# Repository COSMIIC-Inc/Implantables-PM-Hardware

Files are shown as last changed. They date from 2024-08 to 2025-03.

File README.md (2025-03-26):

# Implantables-PowerModule-Hardware Read Me

## Contents
This repository is home to the 3D CAD and PCB design files of the PM2 - Power Module in the COSMIIC System.
Further documentation is available at **[docs.cosmiic.org/Implantables/PM-Module](https://docs.cosmiic.org/Implantables/PM-Module)**

## Licensing
Hardware-related files are licensed to open source users by COSMIIC under the CERN Open Hardware License - Permissive - v2 (CERN-OHL-P-2.0). Refer to the **[license text](https://ohwr.org/cern_ohl_p_v2.txt)** (also embedded in the repository as **LICENSE.txt**) and **[user guide](https://ohwr.org/project/cernohl/-/wikis/uploads/8a6b5d01f71c207c49493e4d114d61e6/cern_ohl_p_v2_howto.pdf)** to understand your permissions.

Hardware-related files includes, but is not limited to...

- Mechanical Design
    - 3D CAD Files (parts and assemblies, multiple file types)
    - Mechanical Drawings (parts and assemblies, mulitple file types)
- PCB Design
    - Fabrication (Gerber and Drill files)
    - Assembly (Pick and Place, BOM)
    - Archive (Schematics, multiple file types)

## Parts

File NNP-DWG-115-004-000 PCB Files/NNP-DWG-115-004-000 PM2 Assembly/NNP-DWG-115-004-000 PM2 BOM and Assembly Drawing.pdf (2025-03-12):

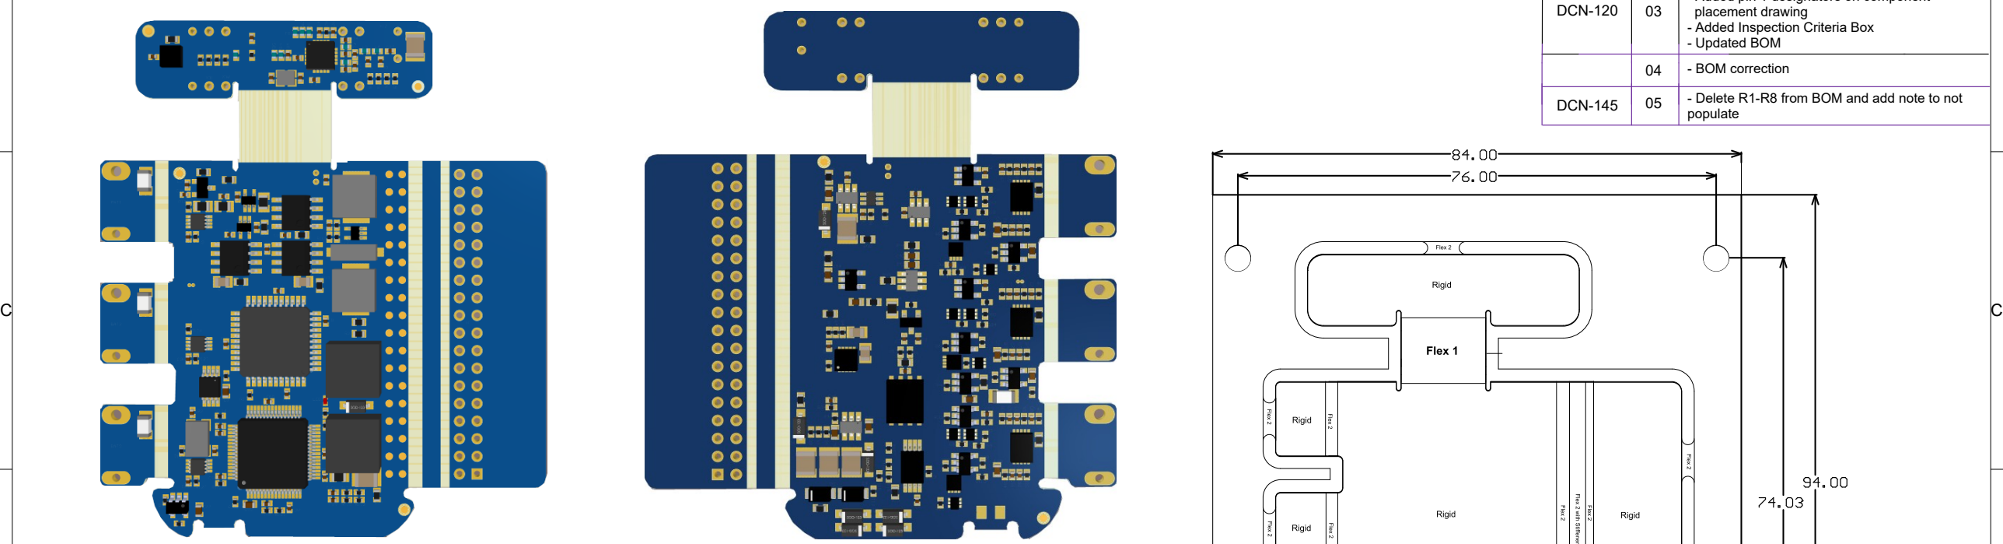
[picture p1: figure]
placement drawing - Added Inspection Criteria Box - Updated BOM; - BOM correction; populate; DCN-145

D | D

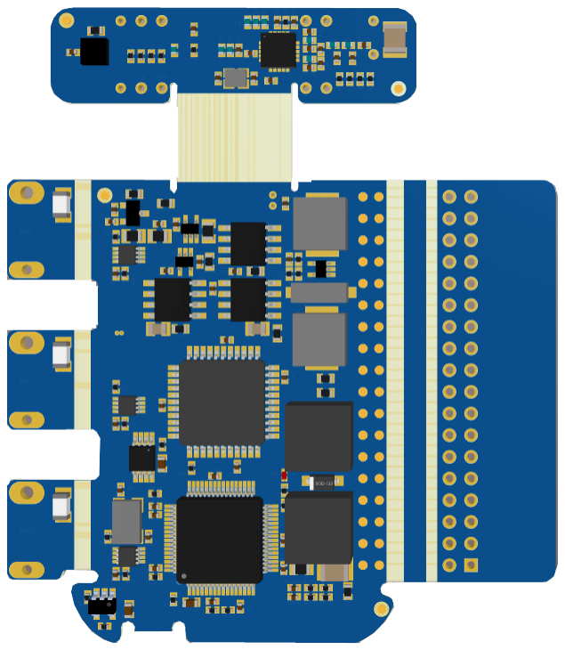
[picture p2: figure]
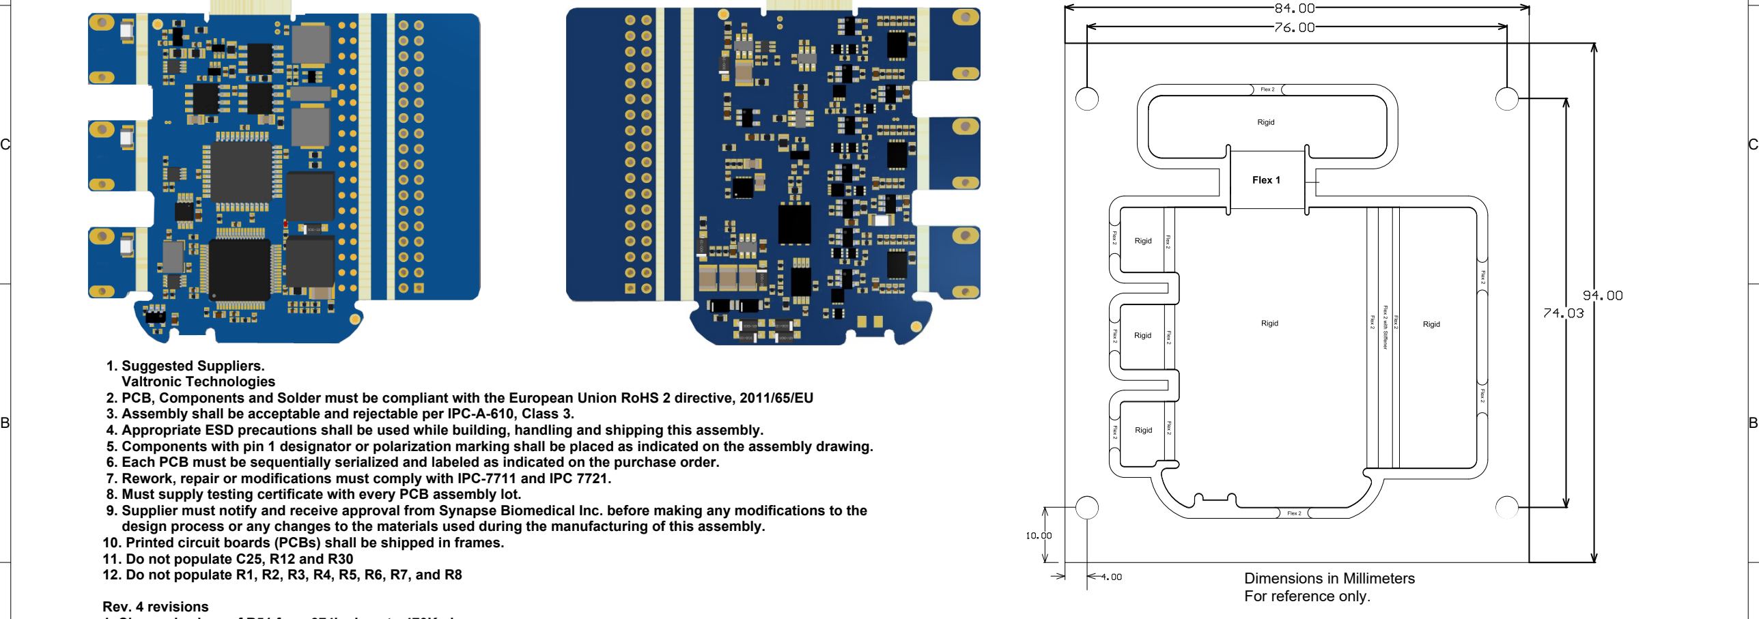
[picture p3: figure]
1. Suggested Suppliers. Valtronic Technologies; 11. Do not populate C25, R12 and R30; Rev. 4 revisions; Dimensions in Millimeters For reference only.

A | A
INSPECTION REQUIRED | YES | NO | DRAWN K. Kowalski | 07-18-2022
| X
CERTIFICATE REQUIRED | YES | NO | CHECKED T. Crish | 07-18-2022
| X

Insp. Item
A | Inspect to current 51-2001-08 Inspection Procedure
| REF 51-2001-09 Inspect report
C | RoHS Certificate required

D
51-2001 | 5

NNP Power Module (PM1)
PCB Assembly Drawing

DOCUMENT NAME

DOCUMENT NO. | REV

NEXT ASSY
SCALE:

B

SIZE
FINISH

MATERIAL

BY | DATE

SHEET 1 OF 6

ECN | REV | DESCRIPTION
DCN-104 DCN-110 | | Initial Engineering Released. Never Build.

N/A

- Updated BOM (refer to Page 1 of the Schematic for changes)
- Added component placement
- Updated Notes
Top | Bottom
2. PCB, Components and Solder must be compliant with the European Union RoHS 2 directive, 2011/65/EU
3. Assembly shall be acceptable and rejectable per IPC-A-610, Class 3.
4. Appropriate ESD precautions shall be used while building, handling and shipping this assembly.
5. Components with pin 1 designator or polarization marking shall be placed as indicated on the assembly drawing.
6. Each PCB must be sequentially serialized and labeled as indicated on the purchase order.
7. Rework, repair or modifications must comply with IPC-7711 and IPC 7721.
8. Must supply testing certificate with every PCB assembly lot.
9. Supplier must notify and receive approval from Synapse Biomedical Inc. before making any modifications to the design process or any changes to the materials used during the manufacturing of this assembly.
10. Printed circuit boards (PCBs) shall be shipped in frames.

### 12. Do not populate R1, R2, R3, R4, R5, R6, R7, and R8

### 1. Changed values of R51 from 374k ohms to 470K ohms

2. Changed R52 from 43.2k ohm to 69.8K Ohm.
3. Changed resistor R14 from 0.0 ohm to 3k ohm.
4. Changed R106 and R107 from 10.0k ohm to 1.5k ohm.
5. Changed C40, C41, C42 and C56 to a smaller package Capacitor.

Rev. 5 revision

### 1. Added note to not populate R1-R8 2. Delete R1-R8 from BOM

DCN-120 03

- Updated Notes
- Added pin 1 designators on component
N/A | N/A
Note: Program CPLD U7 with PM20 Code | N/A

INSPECTION CRITERIA

E

05 - Delete R1-R8 from BOM and add note to not

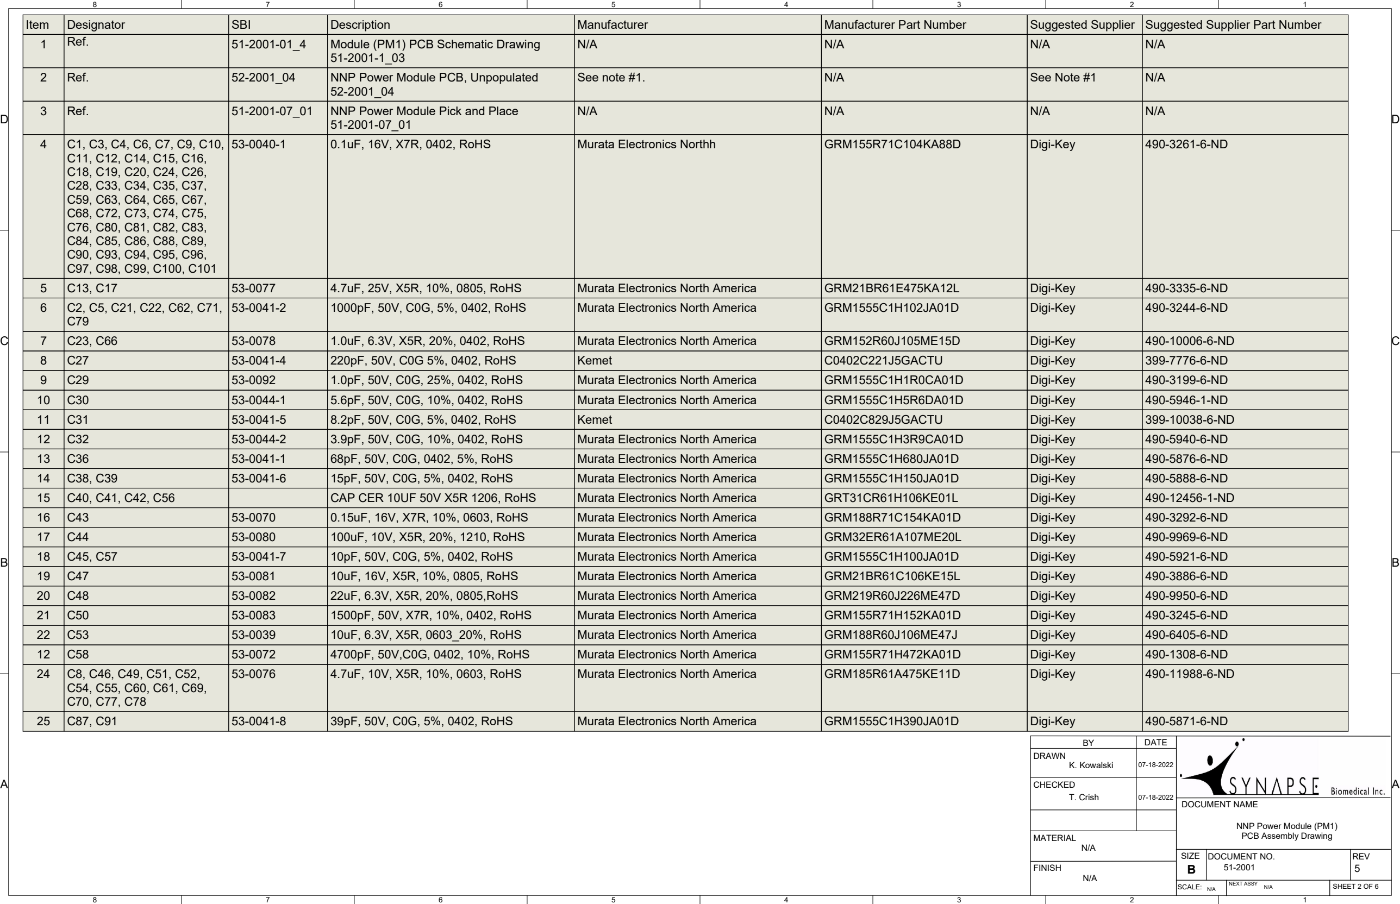
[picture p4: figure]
DATE; CHECKED T. Crish; DRAWN K. Kowalski; DOCUMENT NAME; NNP Power Module (PM1); Item; Designator Ref.; Ref.; SBI 51-2001-01_4; Description Module (PM1) PCB Schematic Drawing 51-2001-1_03 NNP Power Module PCB, Unpopulated 52-2001_04 NNP Power Module Pick and Place 51-2001-07_01 0.1uF, 16V, X7R, 0402, RoHS; 4.7uF, 25V, X5R, 10%, 0805, RoHS 1000pF, 50V, C0G, 5%, 0402, RoHS; 1.0uF, 6.3V, X5R, 20%, 0402, RoHS 220pF, 50V, C0G 5%, 0402, RoHS 1.0pF, 50V, C0G, 25%, 0402, RoHS 5.6pF, 50V, C0G, 10%, 0402, RoHS 8.2pF, 50V, C0G, 5%, 0402, RoHS 3.9pF, 50V, C0G, 10%, 0402, RoHS 68pF, 50V, C0G, 0402, 5%, RoHS 15pF, 50V, C0G, 5%, 0402, RoHS CAP CER 10UF 50V X5R 1206, RoHS 0.15uF, 16V, X7R, 10%, 0603, RoHS 100uF, 10V, X5R, 20%, 1210, RoHS 10pF, 50V, C0G, 5%, 0402, RoHS 10uF, 16V, X5R, 10%, 0805, RoHS 22uF, 6.3V, X5R, 20%, 0805,RoHS 1500pF, 50V, X7R, 10%, 0402, RoHS 10uF, 6.3V, X5R, 0603_20%, RoHS 4700pF, 50V,C0G, 0402, 10%, RoHS 4.7uF, 10V, X5R, 10%, 0603, RoHS; 39pF, 50V, C0G, 5%, 0402, RoHS; Manufacturer; See note #1.; Murata Electronics Northh; Murata Electronics North America Murata Electronics North America; Murata Electronics North America Kemet Murata Electronics North America Murata Electronics North America Kemet Murata Electronics North America Murata Electronics North America Murata Electronics North America Murata Electronics North America Murata Electronics North America Murata Electronics North America Murata Electronics North America Murata Electronics North America Murata Electronics North America Murata Electronics North America Murata Electronics North America Murata Electronics North America Murata Electronics North America; Murata Electronics North America; Manufacturer Part Number; GRM155R71C104KA88D; GRM21BR61E475KA12L GRM1555C1H102JA01D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

D | D
C | C
B | B
A | A
DRAWN K. Kowalski | 07-18-2022
CHECKED T. Crish | 07-18-2022

NNP Power Module (PM1)

DOCUMENT NAME

BY | DATE
N/A | N/A | SHEET 3 OF 6

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
D1, D2, D3, D4, D6, D7, D9

D10

D5, D8
F1, F2, F3, F4

FB1, FB2, FB3, FB4, FB5
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
LED1
R17, R27, R101
R10
R100, R104
R102
R11, R13, R16, R18, R19,
R20, R21, R22, R24, R29,
R31, R32, R37, R39, R45,
R46, R47, R48, R49, R50
R14

R118
R125
R15, R60, R61, R65, R68,
R77, R78, R81, R83, R92,
R93, R96, R98
R23
R25

54-0084

54-0112

54-0111
54-0113

54-0114
53-0094
53-0089-4
53-0089-3
53-0089-2
53-0089-1
53-0090
54-0115
54-0116
54-0117
53-0035
53-0048
53-0049-22
53-0088
53-0049-35
53-0075

53-0049-36
53-0049-11
53-0049-4

53-0023-03
53-0084

0.1uF, 50V, X7R, 10%, 0603, RoHS Schottky Diode, 40V, 500mA, SOD123, RoHS
Schottky Diode, 20V, 1000mA, SOD123W, RoHS
Zener Diode, 15V, 1W, DI123, RoHS
PTC Resettable, 500mA, 0.4 ohm, 6V, 1206, RoHS
Ferrite, 100mA, 1ohm, 0402, RoHS Ferrite, 250mA, 1.1ohm, 0402, RoHS
47nF, 0402, 5%, RoHS
33nH, 0402, 5%, RoHS
27nH, 0402, 5%, RoHS
18nH, 0402, 5%, RoHS
47uH, 830mA, 20%, RoHS
10uH, 1.6A, 20%, 3030, RoHS
10uH, 1.1A, 2626, 20%, RoHS
2.7uH, 1.8A, 2626, 20%, RoHS
LED, Red, 0402, 20mA ,2V, 140mcd, RoHS 0.0 ohm, 1/16W, 0402, RoHS
7.5k ohm, 0.1%, 1/16W, 0402, RoHS
0.0 ohm, 1/8W, 0805, RoHS
38.3k ohm, 1%, 1/16W, 0402, RoHS 0.0 ohm, 1/16W, 0603, RoHS

3.0k ohm, 1/5W, 1%, 0402, RoHS

549k ohm, 1%, 1/16W, 0402, RoHS 150k ohm, 1%, 1/16W, smd, 0402, RoHS 1.0k ohm 1% 1/16W smd 0402 RoHS

20 ohm, 1%, 1/8W, 0805, RoHS 100k ohm, 0.1%, 1/8W, 0805, RoHS

Murata Electronics North America Micro Commercial Co

NXP Semiconductors

Diodes Incorporated
Littelfuse Inc.

Laird-Signal Integrity Products Murata Electronics North America Coilcraft
Coilcraft
Coilcraft
Coilcraft
Pulse
Pulse
Panasonic Electronic Components Panasonic Electronic Components Lumex Opto/Components Inc. Vishay Dale
Vishay Dale
Vishay Dale
Vishay Dale
Vishay Dale

Vishay Dale

Vishay Dale
Vishay Dale
Vishay Dale

Vishay Dale
Vishay Dale

GRM188R71H104KA93D
MBR0540-TP

PMEG2010BER,115

DFLZ15Q-7
1206L050YR

HZ0402A601R-10
BLM15HG102SN1D
0402CS-47NXJLU
0402CS-33NXJLU
0402CS-27NXJLW
0402CS-18NXJLU
P1166.473NLT
P1166.103NLT
ELL-6RH100M
ELL-6RH2R7M
SML-LX0402SIC-TR
CRCW04020000Z0ED
TNPW04027K50BEED
CRCW08050000Z0EA
CRCW040238K3FKED
CRCW06030000Z0EA

CRCW04023K00FKEDHP

CRCW0402549KFKED
CRCW0402150KFKED
CRCW04021K00FKED

CRCW080520R0FKEA
TNPW0805100KBEEA

Supplier
Digi-Key
Digi-Key

Digi-Key

Digi-Key
Digi-Key

Digi-Key
Digi-Key
MOUSER
MOUSER
MOUSER
MOUSER
MOUSER
Digi-Key
Digi-Key
Digi-Key
Digi-Key
Digi-Key
Digi-Key
Digi-Key
Digi-Key
Digi-Key

Digi-Key

Digi-Key
Digi-Key
Digi-Key

Digi-Key
Digi-Key

Supplier Part Number
490-1519-6-ND
MBR0540TPMSDKR-ND

568-6503-6-ND

DFLZ15Q-7DIDKR-ND
F2112DKR-ND

240-2364-1-ND
490-3999-6-ND
994-0402CS-47NXJLU
994-0402CS-33NXJLU
994-0402CS-27NXJLW
994-0402CS-18NXJLU
673-P1166.473TNLT
553-1790-6-ND
PCD1345DKR-ND
PCD1339DKR-ND
67-1878-6-ND
541-0.0JDKR-ND
TNP7.50KDADKR-ND
541-0.0ADKR-ND
541-38.3KLDKR-ND
541-0.0GDKR-ND

541-CRCW04023K00FKEDHPCT-ND

541-549KLDKR-ND
541-150KLDKR-ND
541-1.00KLDKR-ND

541-20.0CDKR-ND
TNP100KABDKR-ND

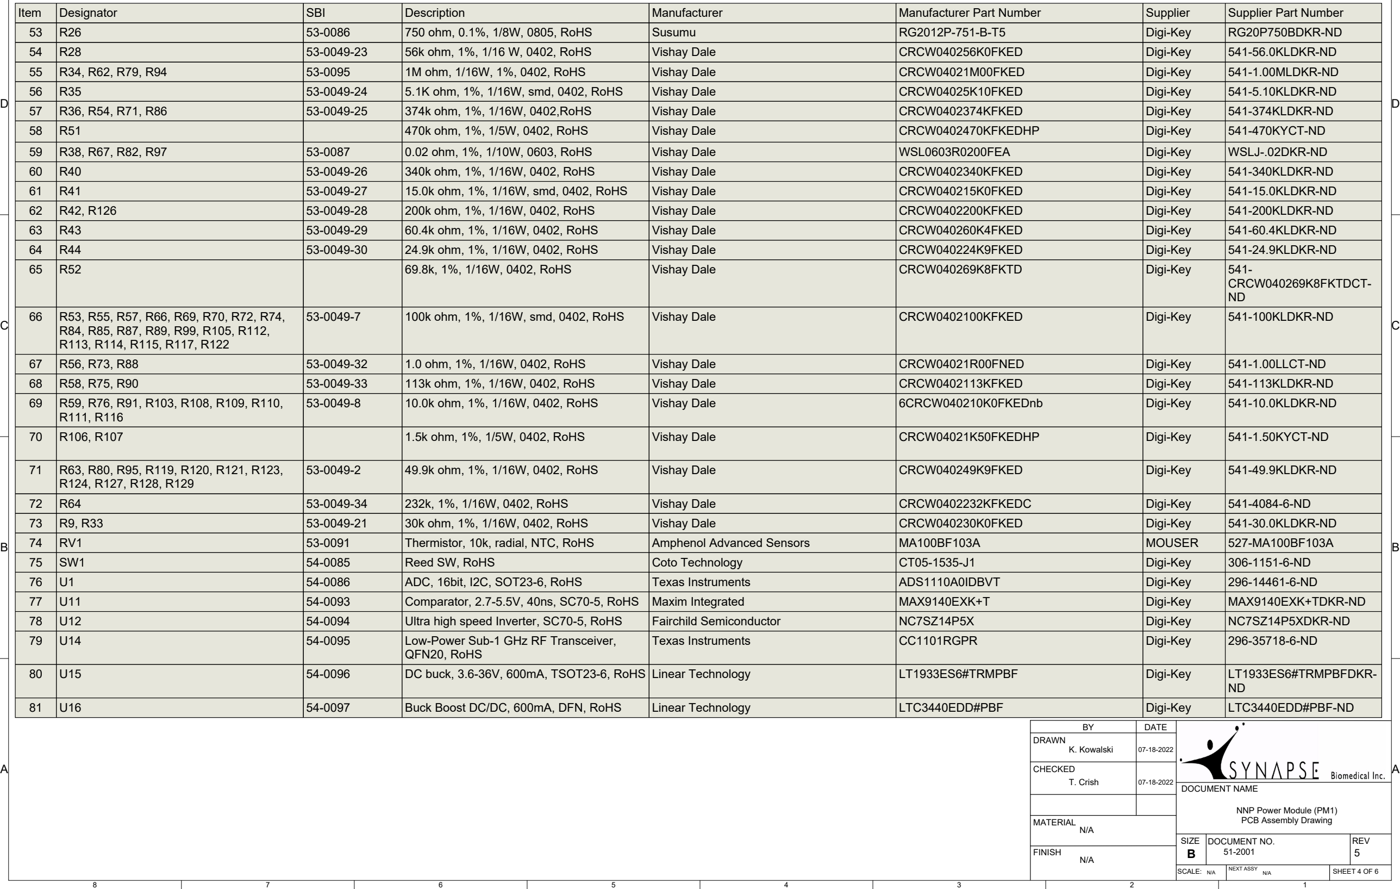
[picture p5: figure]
DATE; CHECKED T. Crish; DRAWN K. Kowalski; DOCUMENT NAME; NNP Power Module (PM1); 750 ohm, 0.1%, 1/8W, 0805, RoHS 56k ohm, 1%, 1/16 W, 0402, RoHS 1M ohm, 1/16W, 1%, 0402, RoHS 5.1K ohm, 1%, 1/16W, smd, 0402, RoHS 374k ohm, 1%, 1/16W, 0402,RoHS 470k ohm, 1%, 1/5W, 0402, RoHS; 0.02 ohm, 1%, 1/10W, 0603, RoHS 340k ohm, 1%, 1/16W, 0402, RoHS 15.0k ohm, 1%, 1/16W, smd, 0402, RoHS 200k ohm, 1%, 1/16W, 0402, RoHS 60.4k ohm, 1%, 1/16W, 0402, RoHS 24.9k ohm, 1%, 1/16W, 0402, RoHS 69.8k, 1%, 1/16W, 0402, RoHS; 100k ohm, 1%, 1/16W, smd, 0402, RoHS; 1.0 ohm, 1%, 1/16W, 0402, RoHS 113k ohm, 1%, 1/16W, 0402, RoHS 10.0k ohm, 1%, 1/16W, 0402, RoHS; 1.5k ohm, 1%, 1/5W, 0402, RoHS; 49.9k ohm, 1%, 1/16W, 0402, RoHS; 232k, 1%, 1/16W, 0402, RoHS 30k ohm, 1%, 1/16W, 0402, RoHS Thermistor, 10k, radial, NTC, RoHS Reed SW, RoHS ADC, 16bit, I2C, SOT23-6, RoHS Comparator, 2.7-5.5V, 40ns, SC70-5, RoHS Ultra high speed Inverter, SC70-5, RoHS Low-Power Sub-1 GHz RF Transceiver, QFN20, RoHS DC buck, 3.6-36V, 600mA, TSOT23-6, RoHS; Buck Boost DC/DC, 600mA, DFN, RoHS; Susumu Vishay Dale Vishay Dale Vishay Dale Vishay Dale Vishay Dale; Vishay Dale Vishay Dale Vishay Dale Vishay Dale Vishay Dale Vishay Dale Vishay Dale; Vishay Dale; Vishay Dale Vishay Dale Vishay Dale; Vishay Dale Vishay Dale Amphenol Advanced Sensors Coto Technology Texas Instruments Maxim Integrated Fairchild Semiconductor Texas Instruments; Linear Technology; RG2012P-751-B-T5 CRCW040256K0FKED CRCW04021M00FKED CRCW04025K10FKED CRCW0402374KFKED CRCW0402470KFKEDHP; WSL0603R0200FEA CRCW0402340KFKED CRCW040215K0FKED CRCW0402200KFKED CRCW040260K4FKED CRCW040224K9FKED CRCW040269K8FKTD; CRCW0402100KFKED; CRCW04021R00FNED CRCW0402113KFKED 6CRCW040210K0FKEDnb; CRCW04021K50FKEDHP; CRCW040249K9FKED; CRCW0402232KFKEDC CRCW040230K0FKED MA100BF103A CT05-1535-J1 ADS1110A0IDBVT MAX9140EXK+T NC7SZ14P5X CC1101RGPR; LT1933ES6#TRMPBF; LTC3440EDD#PBF; Digi-Key Digi-Key Digi-Key Digi-Key; Digi-Key Digi-Key Digi-Key Digi-Key Digi-Key Digi-Key Digi-Key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

D | D
C | C
B | B
A | A
DRAWN K. Kowalski | 07-18-2022
CHECKED T. Crish | 07-18-2022

NNP Power Module (PM1)

DOCUMENT NAME

BY | DATE

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
U17, U26, U34, U42
U18

U19

U2, U13
U20
U21
U22, U30, U38
U23, U29, U31, U37, U39,
U45
U24, U32, U40
U25, U33, U41
U27, U35, U43
U28, U36, U44
U3
U4
U46

U47
U48, U49, U50

U5
U6

U7
U8, U9, U10
Y1
Y2

54-0079

54-0098

54-0087
54-0099
54-0100
54-0101
54-0102

54-0103
54-0104
54-0105
54-0106
54-0088
54-0089
54-0107

54-0060
54-0108

54-0074
54-0090

54-0091
54-0092
54-0109
54-0110

Current Monitor, 2.5V-20V, 1%, RoHS Voltage inverter, 1.15-5.5V, 50mA, SOT23-6, RoHS
Buck Boost, DC/DC, 350mA, SOT23-5, RoHS
Ref, 2.048V, 5uA, SOT23-3, RoHS
DC, Booster, 2.4-16V, TSOT23
DIGPOT, 100Kohm, I2C, SC70
Ideal diode, 2.6-5.5V, 2.6A, SOT23-5, RoHS MOSFET 2N, 60V, 0.305A, RoHS

Dual P-Channel Mosfet, SOT563, RoHS VLDO, 150mA, SOT23-5, RoHS
Op Amp, R-R, 1uA, RoHS
LI-ION Gas Guage, I2C, QFN10, RoHS Flash, 32Mbit, SPI, SO8
RAM, 256Kbit, SPI, TSSOP8, RoHS
uC 1.8Vcore 3.3VIO 16kB RAM 256kB FLA QFP
Voltage detector Reset, SC70-5, RoHS Analog Switch, DUAL, 2-Channel, SSOP8, RoHS
Tri-axis accelerometer, I2C, LGA10, RoHS Precision µPower Oscillator, ADJ 1.7-5.5V,5MHz, uSOP8, RoHS
CPLD, 3.3V, 10nS, XPLA3, QFP48, RoHS Pin driver, 15nS, 40 MHz, SO8, RoHS Xtal, 26MHz, 2.5x2.0x0.7mm, RoHS Crystal 10MHz 20pF HC-49US

Diodes Incorporated
ON Semiconductor

Texas Instruments

Maxim Integrated
Linear Technology
Analog Devices Inc.
Linear Technology
Vishay Siliconix

Vishay Siliconix
Linear Technology
Linear Technology
Texas Instruments
Adesto Technologies
MicroChip Technology
NXP Semiconductors

Texas Instruments
Texas Instruments

Kionix
Linear Technology

Xilinx Inc.
Intersil
NDK
ECS Inc.

ZXCT1010E5TA
NCP1729SN35T1G

LM3670MF-1.8/NOPB

MAX6018AEUR21+T
LT3467AES6#TRMPBF
AD5246BKSZ100-RL7
LTC4411ES5#TRMPBF
SI1026X-T1-GE3

SI1023X-T1-GE3
LTC1844ES5-SD#TRMPBF
LT6003CDC#TRMPBF
BQ27200DRKR
AT45DB321E-SHF-T
23K256T-I/ST
LPC2129FBD64/01,15

TPS3805H33DCKR
TS5A23166DCUR

KXTE9-2050
LTC6930IMS8-5.00#PBF

XCR3032XL-10VQG44C
EL7156CSZ
NX2520SA-26.000000MHZ
ECS-100-20-30B-TR

Digi-Key

Digi-Key

Digi-Key
Digi-Key
Digi-Key
Digi-Key
Digi-Key

Digi-Key
Digi-Key
Digi-Key
Digi-Key
Digi-Key
Digi-Key
Digi-Key

Digi-Key
Digi-key

MOUSER
Digi-Key

Digi-Key
Digi-Key
Digi-Key
Digi-Key

ZXCT1010DKR-ND
NCP1729SN35T1GOSDKR-ND

LM3670MF-1.8/NOPBDKR-ND

MAX6018AEUR21+TDKR-ND
LT3467AES6#TRMPBFDKR-ND
AD5246BKSZ100RLDKR-ND
LTC4411ES5#TRMPBFDKR-ND
SI1026X-T1-GE3CT-ND

SI1023X-T1-GE3CT-ND
LTC1844ES5-SD#TRMPBFDKR-ND LT6003CDC#TRMPBFDKR-ND
296-17521-6-ND
1265-1097-6-ND
23K256T-I/STDKR-ND
568-4315-ND

296-13407-6-ND
296-17906-6-ND

912-KXTE9-2050
LTC6930IMS8-5.00#PBF-ND

122-1957-ND
EL7156CSZ-T7DKR-ND
644-1063-6-ND
XC1117DKR-ND

## Drawing for reference only

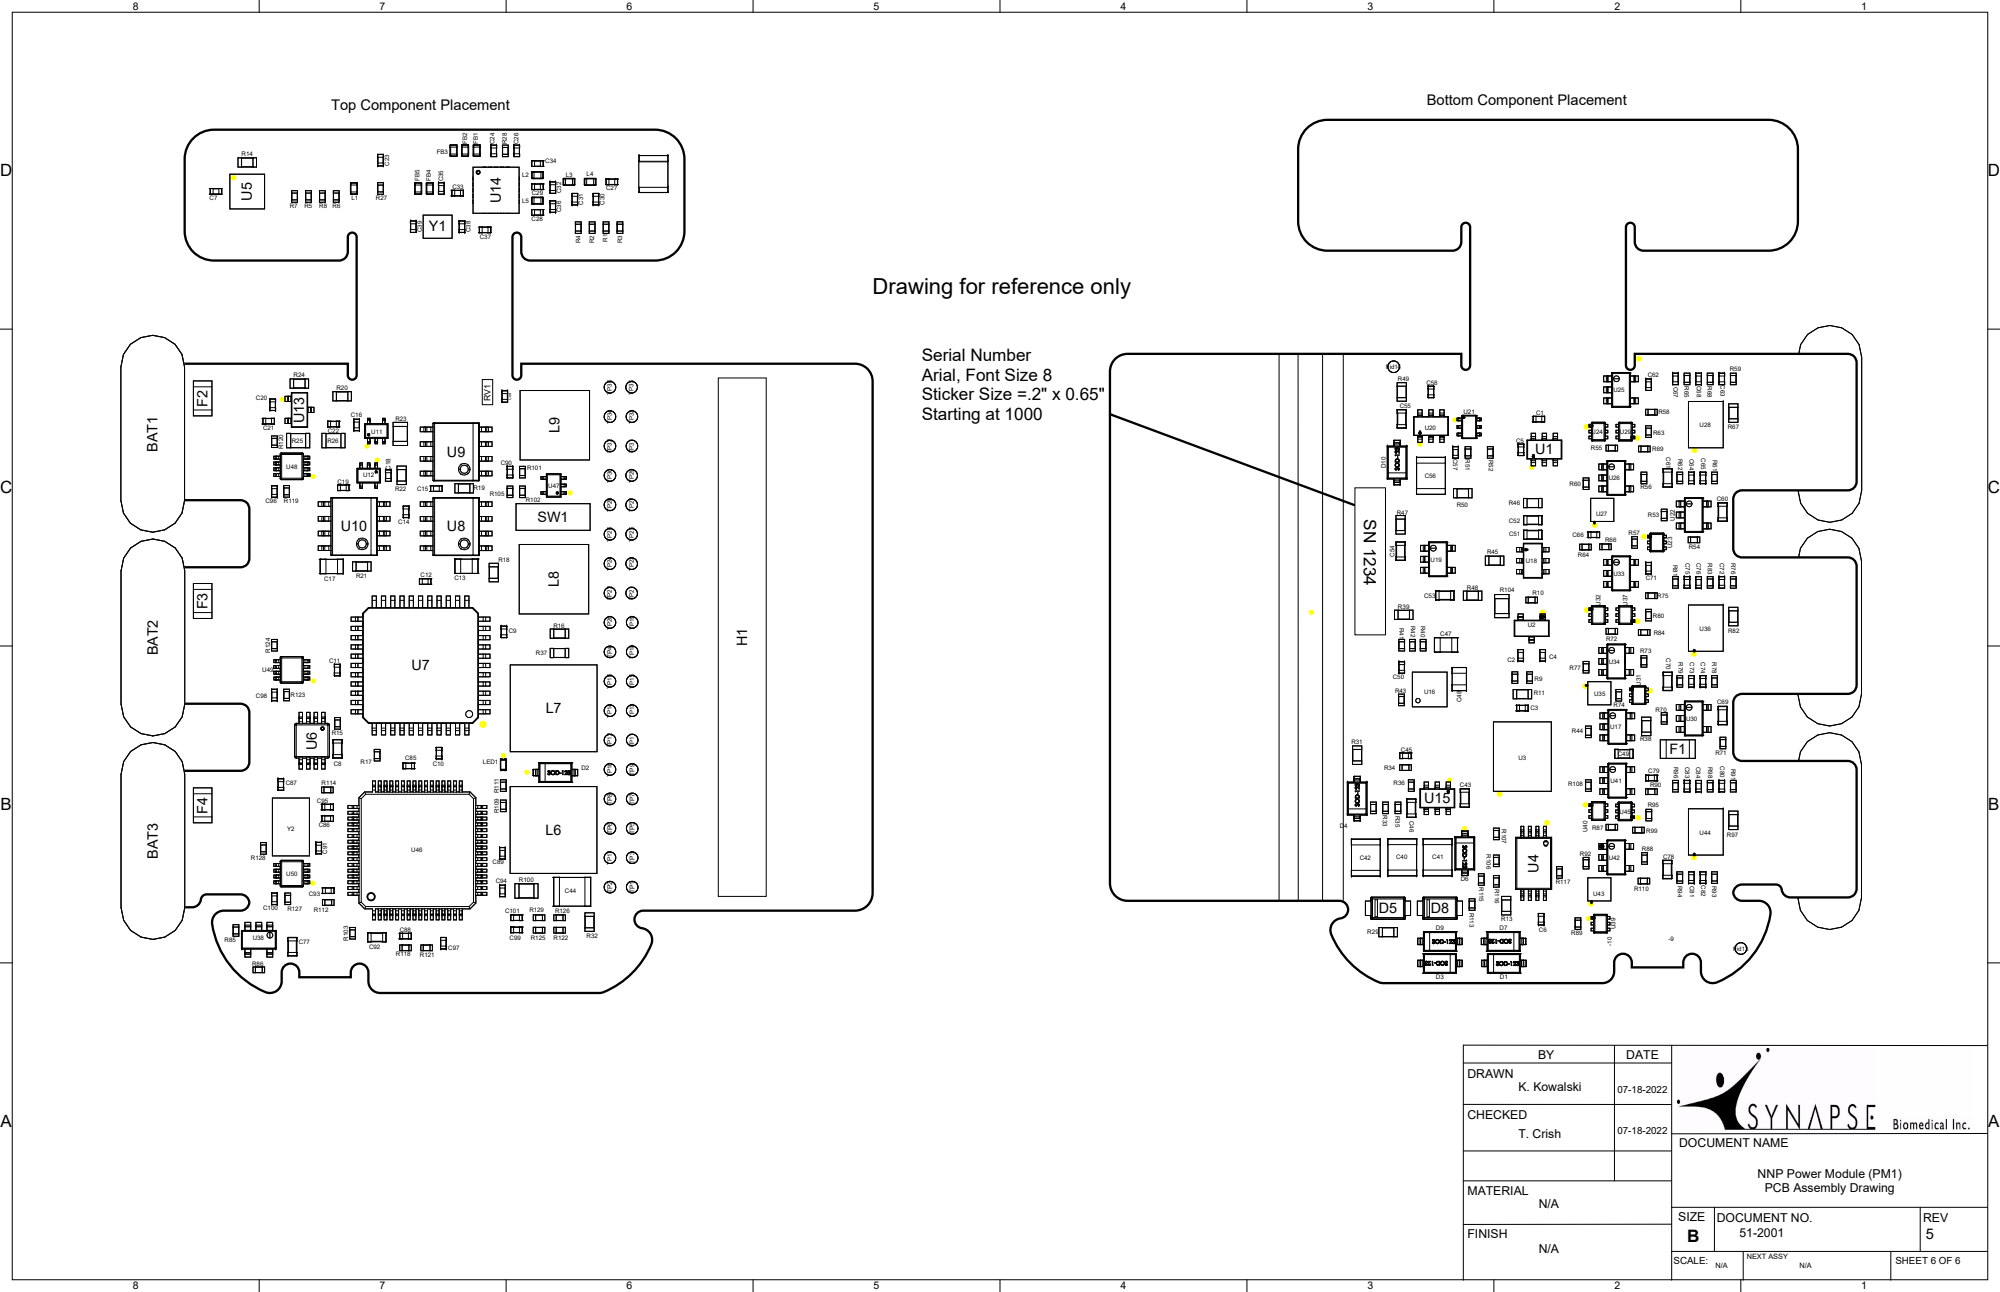
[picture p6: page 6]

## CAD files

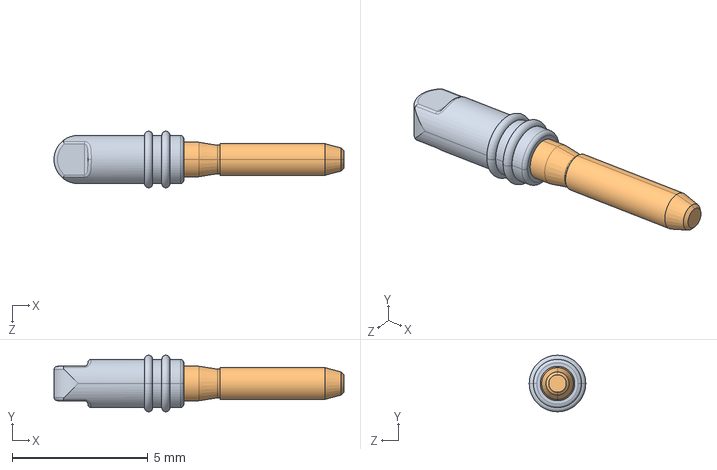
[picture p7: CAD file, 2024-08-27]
Mechanical Design CAD Files/STEP Files/NNP-DWG-115-001-000 Port Plug Assembly.STEP
10.7 x 2.08 x 2.08 mm
NNP-DWG-110-001-000 Port Plug, Handle Overmold, Blue_21-2008 Overmold- Blue
NNP-DWG-110-002-000 Port Plug, Body

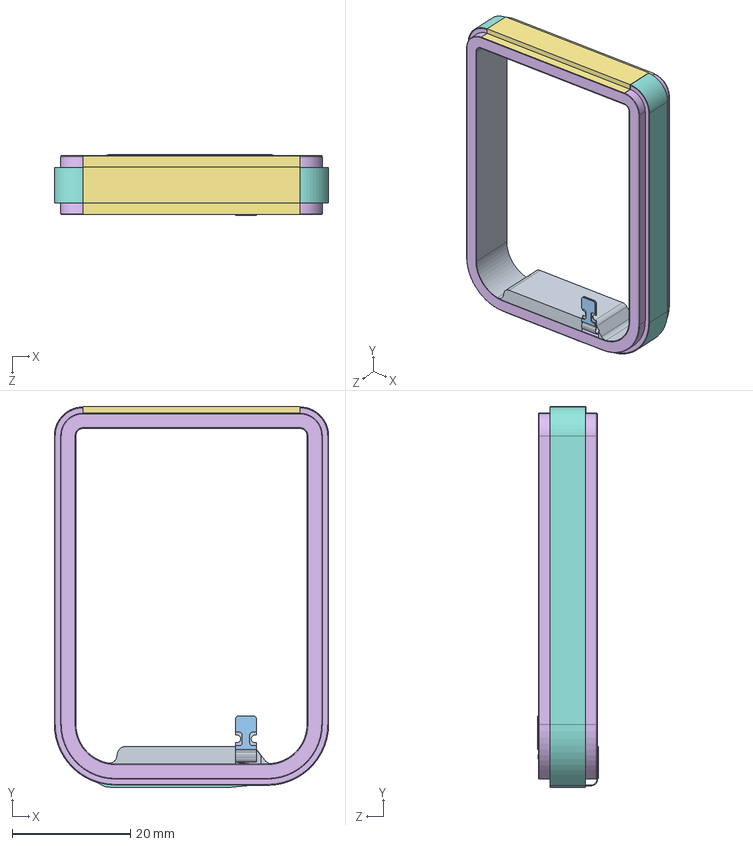
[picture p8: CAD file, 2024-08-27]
Mechanical Design CAD Files/STEP Files/NNP-DWG-115-006-000 Power Module Coil Assembly.STEP
46.5 x 64.5 x 10.3 mm
NNP-DWG-110-017-000 Power Module, Daughter Board
NNP-DWG-110-018-000 Capacitor, 0.22 uF x 2
NNP-DWG-110-019-000 Capacitor, 0.47 uF x 2
NNP-DWG-110-025-000 Recharge Coil

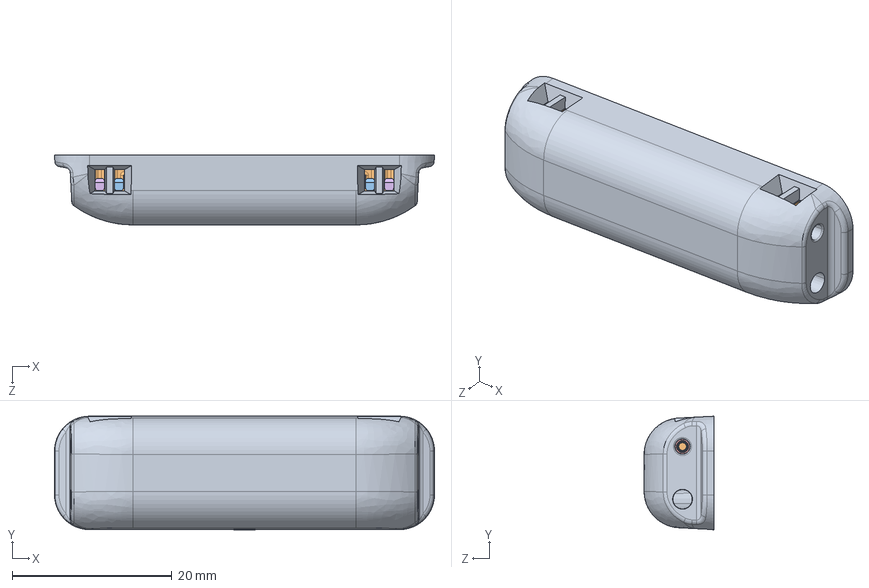
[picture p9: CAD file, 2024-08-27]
Mechanical Design CAD Files/STEP Files/NNP-DWG-115-008-000 Power Module Header Assembly, 2 Port.STEP
47.7 x 14.2 x 8.76 mm
NNP-DWG-110-016-000 Pre-Molded Header, 2-Port
NNP-DWG-110-008-000 BalSeal Block_symmetric part x 2
NNP-DWG-130-011-000 Balseal, Conductor x 2
NNP-DWG-130-012-001 Balseal, Spring, CW x 2
NNP-DWG-130-013-001 Balseal, Washer, CW x 2
NNP-DWG-130-013-002 Balseal, Washer, CCW x 2
NNP-DWG-130-012-002 Balseal, Spring, CCW x 2
NNP-DWG-130-011-000 Balseal, Conductor_No Groove x 2
NNP-DWG-130-005-000 BalSeal Assembly, Internal Cavity Single Seal x 2

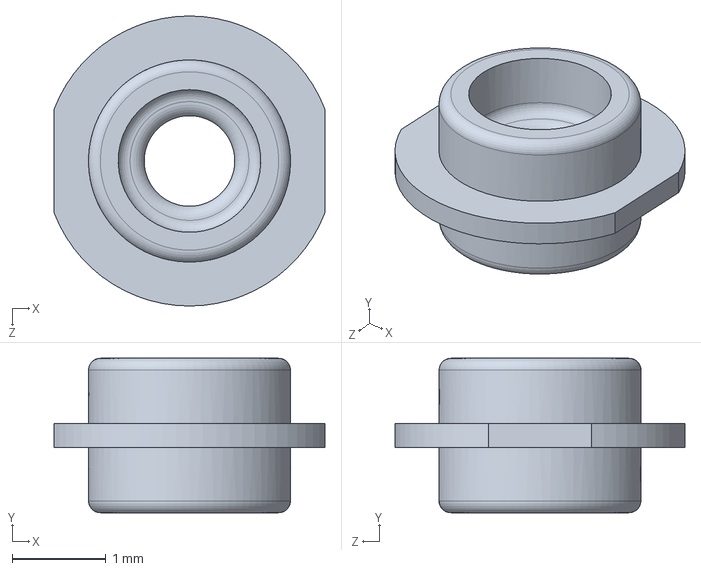
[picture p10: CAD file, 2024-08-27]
Mechanical Design CAD Files/SolidWorks Native Files/NNP-DWG-130-005-000 BalSeal Assembly, Internal Cavity Single Seal.SLDPRT
2.90 x 1.65 x 3.10 mm

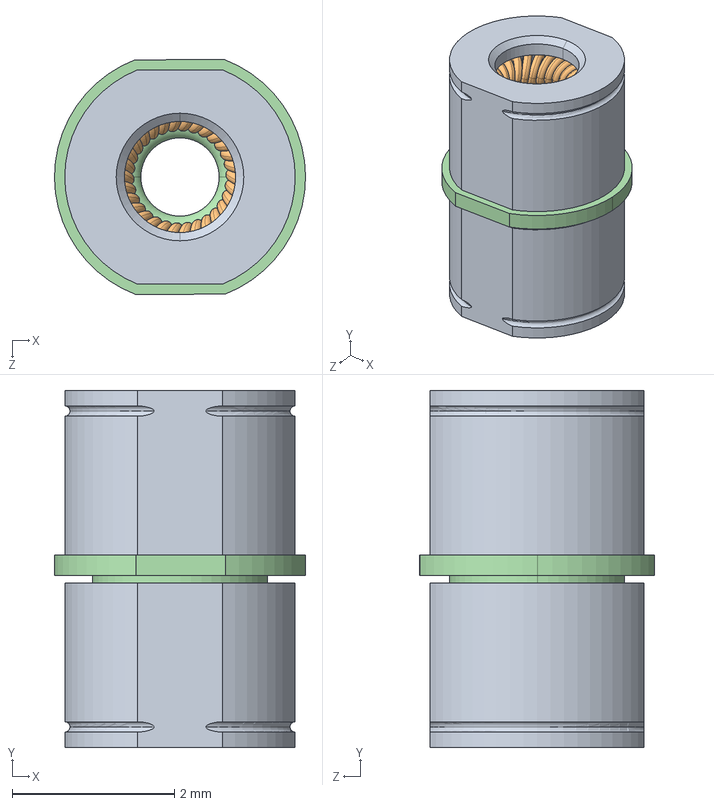
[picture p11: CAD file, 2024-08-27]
Mechanical Design CAD Files/STEP Files/NNP-DWG-135-004-000 SA, BalSeal Stack Assembly.STEP
3.10 x 4.41 x 2.90 mm
NNP-DWG-130-011-000 Balseal, Conductor x 2
NNP-DWG-130-012-001 Balseal, Spring, CW
NNP-DWG-130-013-001 Balseal, Washer, CW
NNP-DWG-130-013-002 Balseal, Washer, CCW
NNP-DWG-130-012-002 Balseal, Spring, CCW
NNP-DWG-130-005-000 BalSeal Assembly, Internal Cavity Single Seal_COMPRESSED

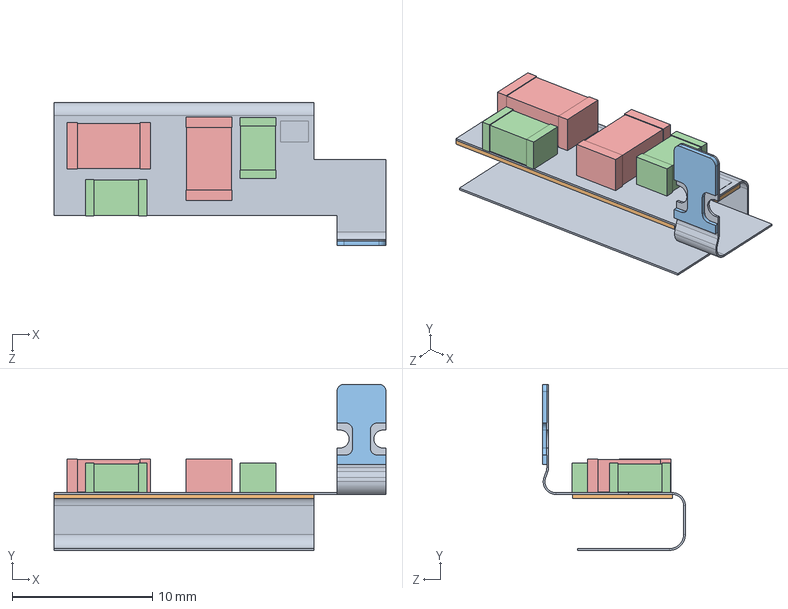
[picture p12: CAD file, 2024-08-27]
Mechanical Design CAD Files/STEP Files/NNP-DWG-115-003-000 SA, Near Field PCB Assembly.STEP
23.7 x 11.9 x 10.2 mm
NNP-DWG-110-017-000 Power Module, Daughter Board
NNP-DWG-110-018-000 Capacitor, 0.22 uF x 2
NNP-DWG-110-019-000 Capacitor, 0.47 uF x 2

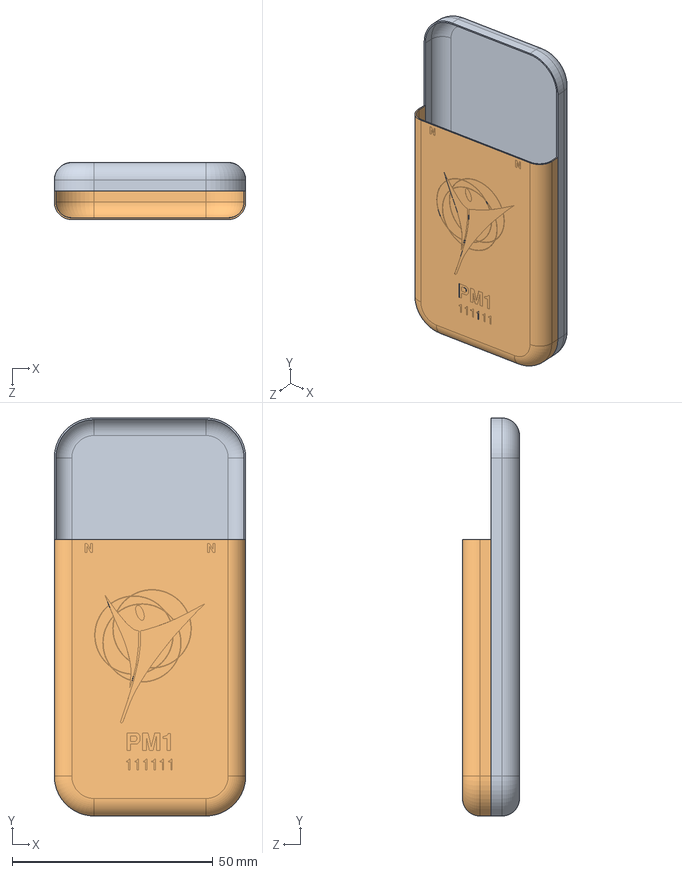
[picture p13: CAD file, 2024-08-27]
Mechanical Design CAD Files/STEP Files/NNP-DWG-115-002-000 SA, Titanium Case.STEP
47.7 x 99.1 x 14.2 mm
NNP-DWG-110-009-000 Case, Uncut Half
NNP-DWG-110-009-000 Case, Uncut Half_Front Artwork

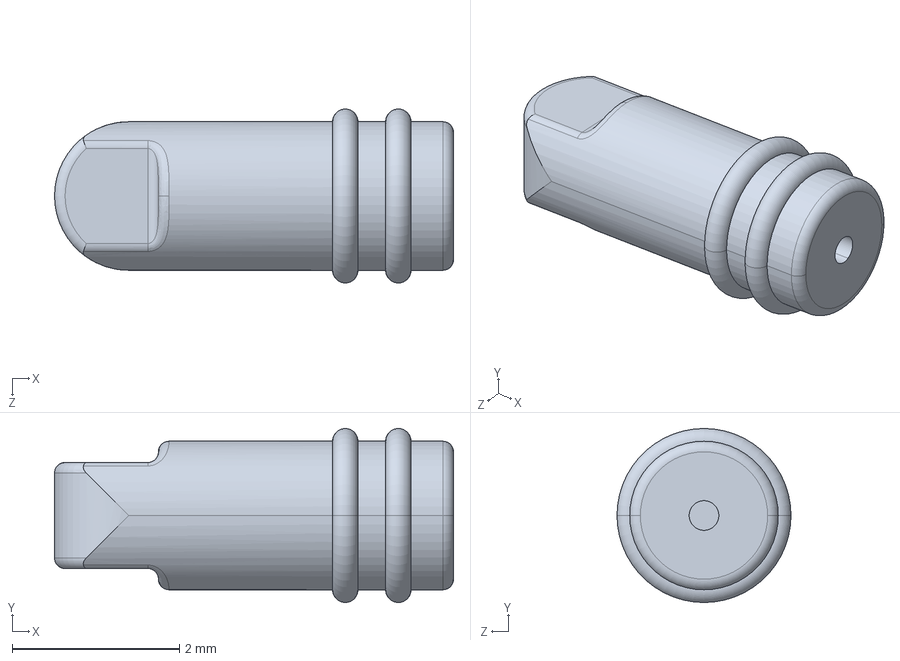
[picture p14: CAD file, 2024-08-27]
Mechanical Design CAD Files/STEP Files/NNP-DWG-110-001-001 Port Plug, Handle Overmold, Red.STEP
4.78 x 2.08 x 2.08 mm

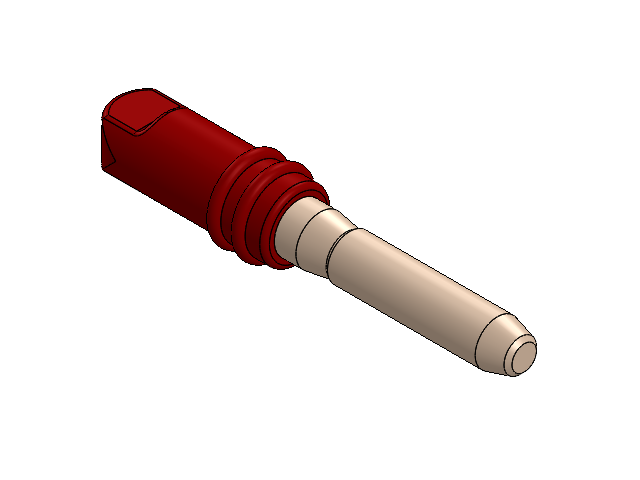
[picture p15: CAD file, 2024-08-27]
Mechanical Design CAD Files/SolidWorks Native Files/NNP-DWG-115-001-000 Port Plug Assembly.SLDASM
NNP-DWG-110-001-000 Port Plug, Handle Overmold, Blue
NNP-DWG-110-002-000 Port Plug, Body
NNP-MAT-150-011-000 NuSil Med-4850
NNP-MAT-150-013-000 NuSil Med-165, Silicone Primer
NNP-MAT-150-002-000 Primer, Med6-161
NNP-MAT-150-012-007 NuSil Med-4800, Blue

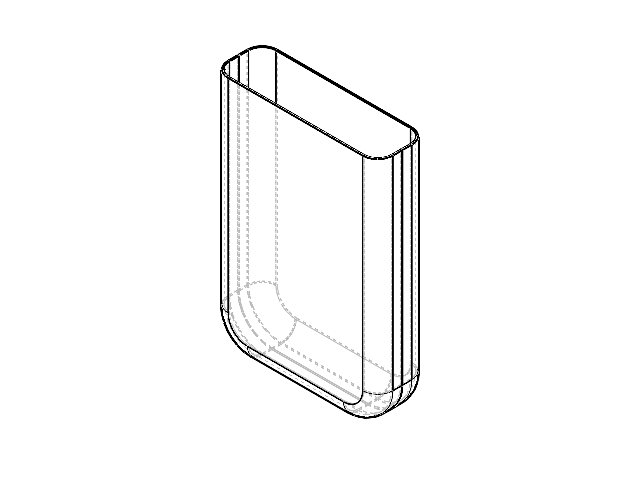
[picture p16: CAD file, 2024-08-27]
Mechanical Design CAD Files/SolidWorks Native Files/NNP-DWG-110-010-000 Case, Trimmed.SLDASM
NNP-DWG-110-009-000 Case, Uncut Half x 2

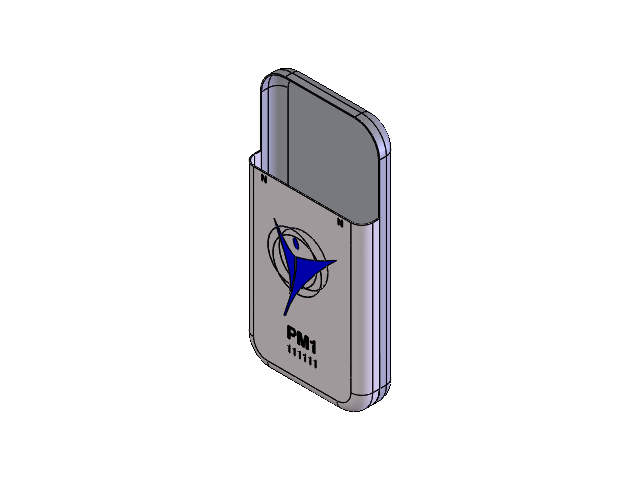
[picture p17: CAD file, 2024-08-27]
Mechanical Design CAD Files/SolidWorks Native Files/NNP-DWG-115-002-000 SA, Titanium Case.SLDASM
NNP-DWG-110-009-000 Case, Uncut Half x 2

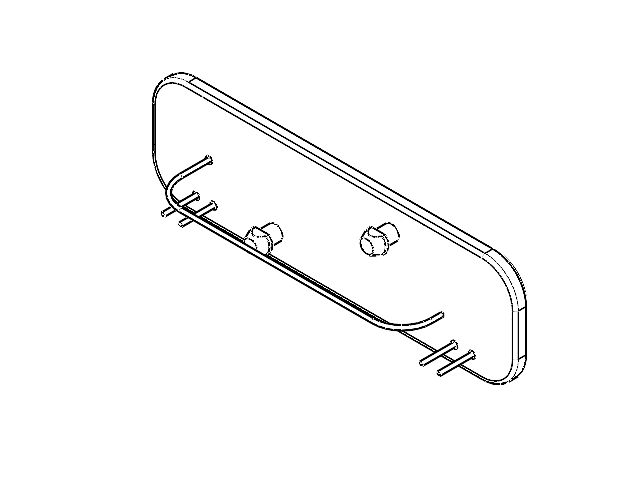
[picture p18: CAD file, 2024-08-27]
Mechanical Design CAD Files/SolidWorks Native Files/NNP-DWG-115-007-000 Power Module Feedthrough Insulator.SLDASM
NNP-DWG-110-014-000 Lidthrough, Flange, 2 Port, Kryoflex
NNP-DWG-110-005-000 Antenna Wire
NNP-DWG-110-013-000 Feedthrough Pin, Short x 4
NNP-DWG-110-012-000 Lidthrough, Anchor Pin x 2
NNP-DWG-110-006-000 Case, Connection Wire

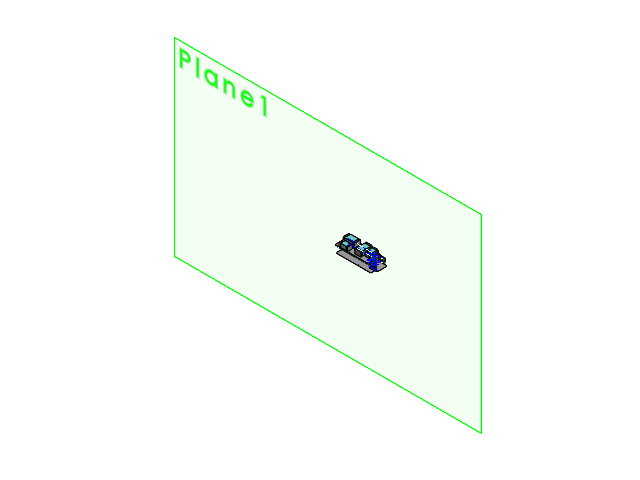
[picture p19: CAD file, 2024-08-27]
Mechanical Design CAD Files/SolidWorks Native Files/NNP-DWG-115-003-000 SA, Near Field PCB Assembly.SLDASM
NNP-DWG-110-017-000 Power Module, Daughter Board
NNP-DWG-110-018-000 Capacitor, 0.22 uF x 2
NNP-DWG-110-019-000 Capacitor, 0.47 uF x 2

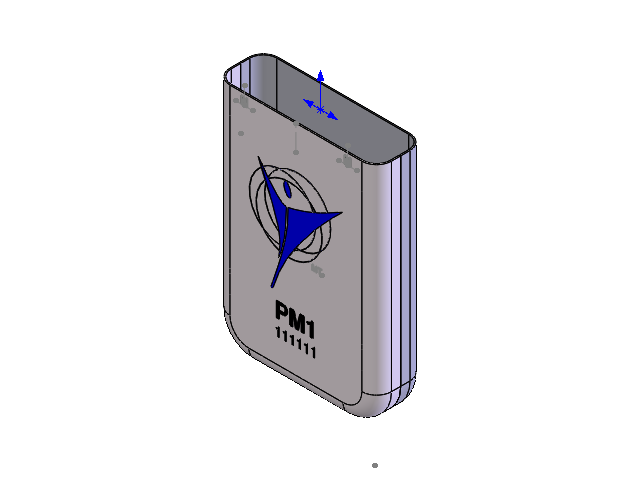
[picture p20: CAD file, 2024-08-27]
Mechanical Design CAD Files/SolidWorks Native Files/NNP-DWG-110-011-000 Case, Power Module Marking.SLDASM
NNP-DWG-110-009-000 Case, Uncut Half x 2

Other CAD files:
Mechanical Design CAD Files/STEP Files/NNP-DWG-130-005-000 BalSeal Assembly, Internal Cavity Single Seal.STEP
Mechanical Design CAD Files/SolidWorks Native Files/NNP-DWG-115-006-000 Power Module Coil Assembly.SLDASM
Mechanical Design CAD Files/SolidWorks Native Files/NNP-DWG-115-005-000 SA, Battery.SLDASM
Mechanical Design CAD Files/SolidWorks Native Files/NNP-DWG-135-002-000 SA, Balseal, CW.SLDASM
Mechanical Design CAD Files/STEP Files/NNP-DWG-110-001-000 Port Plug, Handle Overmold, Blue.STEP
Mechanical Design CAD Files/STEP Files/NNP-DWG-110-001-002 Port Plug, Handle Overmold, Green.STEP
Mechanical Design CAD Files/STEP Files/NNP-DWG-110-002-000 Port Plug, Body.STEP
Mechanical Design CAD Files/STEP Files/NNP-DWG-110-003-000 Suture Skirt.STEP
Mechanical Design CAD Files/STEP Files/NNP-DWG-110-004-000 Antenna Support.STEP
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

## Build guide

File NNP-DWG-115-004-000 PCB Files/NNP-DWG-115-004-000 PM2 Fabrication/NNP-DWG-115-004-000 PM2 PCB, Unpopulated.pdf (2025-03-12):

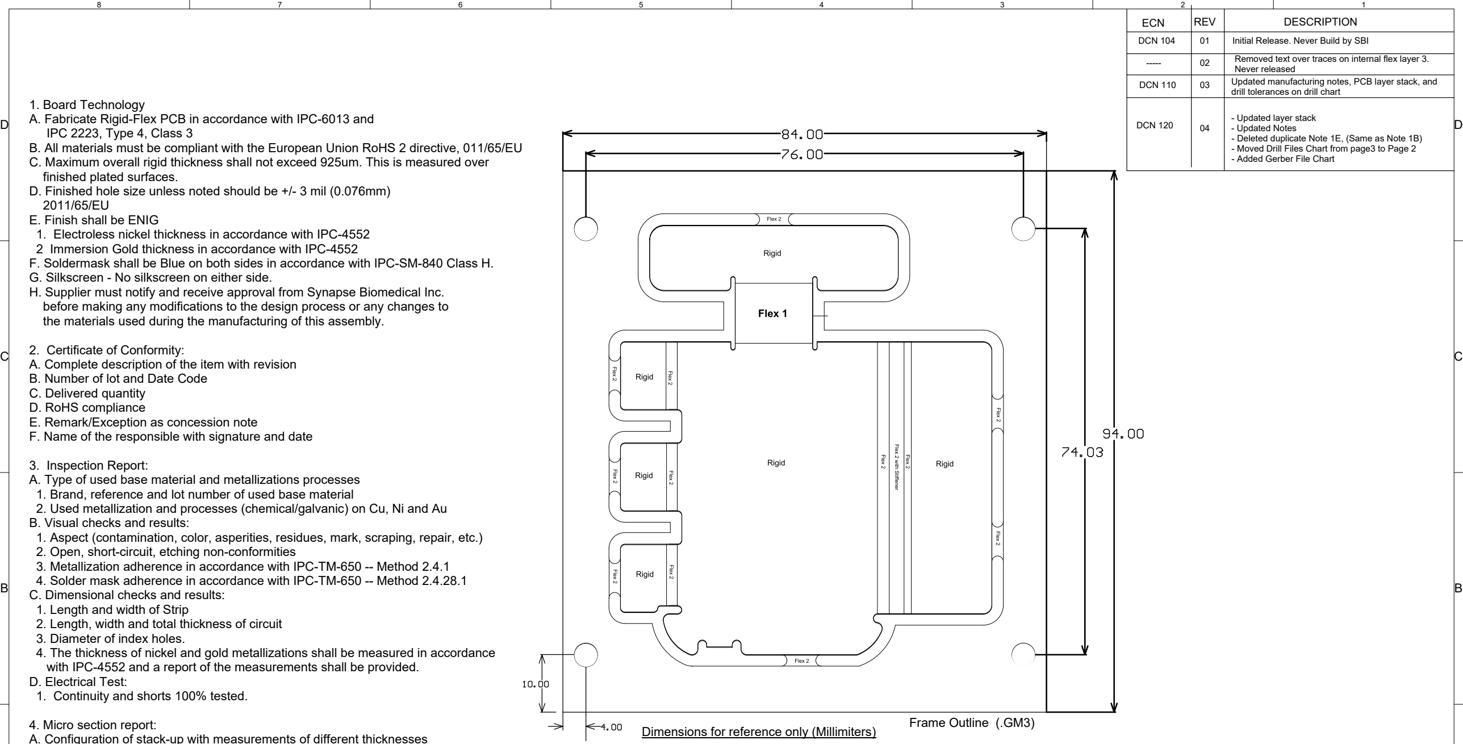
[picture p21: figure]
ECN; REV; DESCRIPTION; DCN 110; drill tolerances on drill chart; Dimensions for reference only (Millimiters); Frame Outline (.GM3); Never released; DCN 120; - Added Gerber File Chart; 1. Board Technology; IPC 2223, Type 4, Class 3; finished plated surfaces.; 2011/65/EU E. Finish shall be ENIG; 2. Certificate of Conformity:; B. Number of lot and Date Code C. Delivered quantity D. RoHS compliance E. Remark/Exception as concession note; 3. Inspection Report:; B. Visual checks and results:; C. Dimensional checks and results: 1. Length and width of Strip; 3. Diameter of index holes.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

A | 10-4-2018 | A
DRAWN R. Yoder | 10-4-2018

CHECKED A. Zbrzeski

52-2001 | 04

NNP Power Module PCB,
Unpopulated

DOCUMENT NAME

DOCUMENT NO. | REV

NEXT ASSY

B

SIZE
FINISH

MATERIAL

BY | DATE

SHEET 1 OF 6

SEE NOTES

SEE NOTES

DCN 104 | 01 | Initial Release. Never Build by SBI

Updated manufacturing notes, PCB layer stack, and

Removed text over traces on internal flex layer 3.

- Deleted duplicate Note 1E, (Same as Note 1B)
- Moved Drill Files Chart from page3 to Page 2
A. Fabricate Rigid-Flex PCB in accordance with IPC-6013 and
B. All materials must be compliant with the European Union RoHS 2 directive, 011/65/EU
C. Maximum overall rigid thickness shall not exceed 925um. This is measured over
D. Finished hole size unless noted should be +/- 3 mil (0.076mm)
1. Electroless nickel thickness in accordance with IPC-4552
2 Immersion Gold thickness in accordance with IPC-4552
F. Soldermask shall be Blue on both sides in accordance with IPC-SM-840 Class H.
G. Silkscreen - No silkscreen on either side.
H. Supplier must notify and receive approval from Synapse Biomedical Inc.
before making any modifications to the design process or any changes to
the materials used during the manufacturing of this assembly.
A. Complete description of the item with revision
F. Name of the responsible with signature and date
A. Type of used base material and metallizations processes
1. Brand, reference and lot number of used base material
2. Used metallization and processes (chemical/galvanic) on Cu, Ni and Au
1. Aspect (contamination, color, asperities, residues, mark, scraping, repair, etc.)
2. Open, short-circuit, etching non-conformities
3. Metallization adherence in accordance with IPC-TM-650 -- Method 2.4.1
4. Solder mask adherence in accordance with IPC-TM-650 -- Method 2.4.28.1
2. Length, width and total thickness of circuit
4. The thickness of nickel and gold metallizations shall be measured in accordance with IPC-4552 and a report of the measurements shall be provided.
A. Configuration of stack-up with measurements of different thicknesses
B. Thickness of Copper metallization.
5. Solderability test report:
A. Result of the solderability test according to ANSI/J-STD-003 -- Category 2 Test A -Hand Dipped

D | D
C | C
B | B
A | A
BY | DATE
DRAWN R. Yoder | 10-4-2018
CHECKED A. Zbrzeski | 10-4-2018

DOCUMENT NAME

NNP Power Module PCB,

Flex Area 1

Flex Coverlay Top, 2.0mil, MCL Plus 110 Layer 4, 0.7mil, Copper
Dielectric (Core), 2.0mil, Polyimide RF775 0.002 H/H
Layer 5, 0.7mil, Copper
Flex Coverlay Bottom, 2.0mil, MCL Plus 110

Rigid Area
Paste Mask, GTP
Solder Mask, 1.0mil, GTS
Layer 1, 0.5 oz base, 0.7mil, Copper, GTL Dielectric, 2.75mil, Prepreg 1080NF IT 180A Layer 2, 0.7mil, Copper, G1
Dielectric, 6.0mil, FR4 0.006 IT 180A
Layer 3, 0.7mil, Copper, G2
Dielectric, 5.5mil, Prepreg 1080NF IT 180A Layer 4, 0.7mil, Copper, G3
Dielectric (Core), 2.0mil, Polyimide RF775 0.002 H/H
Layer 5, 0.7mil, Copper, G4
Dielectric, 5.5mil, Prepreg 1080NF IT 180A Layer 6, 0.7mil, Copper, G5
Dielectric, 6.0mil, FR4 0.006 IT 180A
Layer 7, 0.7mil, Copper, G6
Dielectric, 2.75mil, Prepreg 1080 NFIT 180A Layer 8, 0.5 oz base, 0.7mil, Copper, GBL Paste Mask, GBP
Solder Mask, 1.0mil, GBS

Flex Area 2

Flex Coverlay, 2.0mil, MCL Plus 110 Layer 4, 0.7mil, Copper
Dielectric (Core), 2.0mil, Polyimide RF775 0.002 H/H
Flex Coverlay, 2.0mil, MCL Plus 110

Flex Area 2 with Stiffener

Core, 12.0mil, 0.012 IT 180A
Flex Bond-Ply, 1.0mil, PSA
Flex Coverlay Top, 2.0mil, MCL Plus 110 Layer 4, 0.7mil, Copper
Dielectric (Core), 2.0mil, Polyimide RF775 0.002 H/H
Flex Coverlay Bottom, 2.0mil, MCL Plus 110 Flex Bond-Ply, 1.0mil, PSA
Core, 12.0mil, 0.012 IT 180A

# Layer Stack

See Notes

.GD1 Rev. 04
.GD2 Rev. 04
.GD3 Rev. 04
.GG1 Rev. 04
.GG2 Rev. 04
.GG3 Rev. 04
.TXT Rev. 04
.TXT1 Rev. 04
.TXT2 Rev. 04
.apr Rev. 04

Drill Table 1, L1 Top - L8 Bottom Drill Table 2, L1 Top - L2 Ground 1 Drill Table 3, L8 Bottom - L7 Ground 2 Drill Guide 1, L1 Top - L8 Bottom Drill Guide 2, L1 Top - L2 Ground 1 Drill Guide 3, L8 Bottom - L7 Ground 2 NC Drill 1, L1 Top - L8 Bottom
NC Drill 2, L1 Top - L2 Ground 1
NC Drill 3, L8 Bottom - L7 Ground 2 Aperture APR File
.GTO Rev. 04 | Drill Files

.GTP Rev.04
.GTS Rev. 04
.GTL Rev. 04
.G1 Rev. 04
.G2 Rev.04
.G3 Rev. 04
.G4 Rev. 04
.G5 Rev. 04
.G6 Rev. 04
.GBL Rev. 04
.GBS Rev. 04
.GBP Rev. 04
.GBO Rev. 04
.GM3 Rev. 04

Top Overlay
Top Paste
Top Mask
Top Copper
Layer 2 GND, Plane
Layer 3 Rigid, Singal 1
Layer 4 Flex, Singal 2
Layer 5 Flex, Signal3
Layer 6 3.3V, Plane
Layer 7 GND, Plane
Bottom Copper
Bottom Mask
Bottom Paste
Bottom Overlay
Frame Outline

# Gerber Files

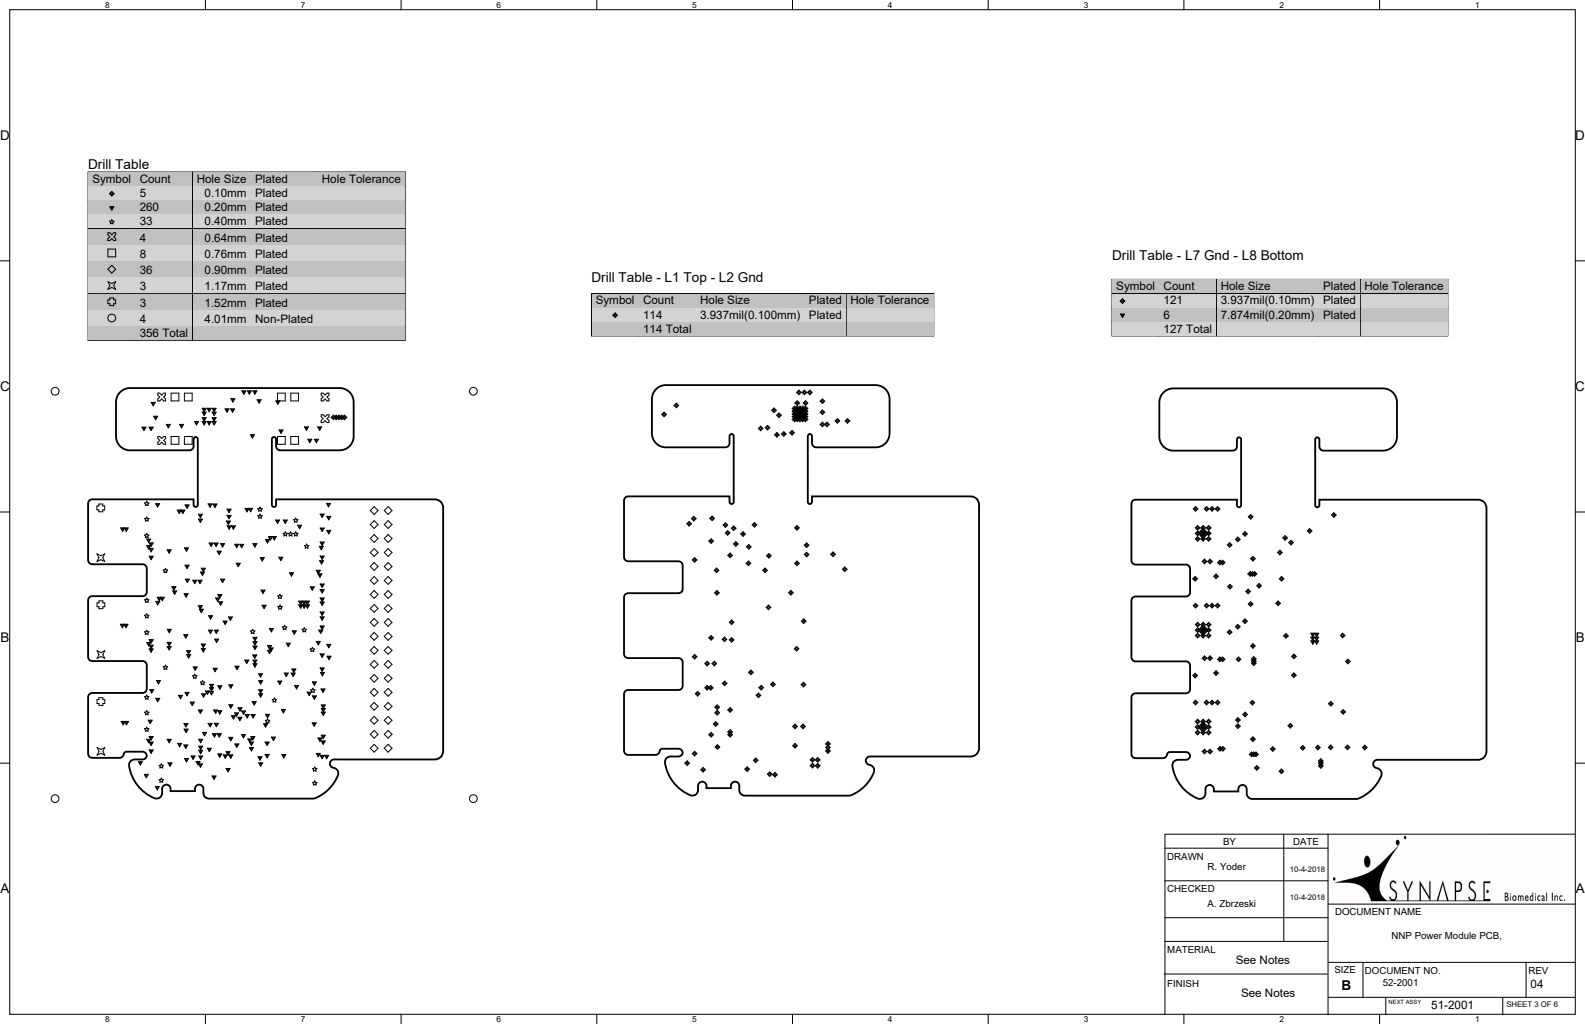
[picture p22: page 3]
DATE; DOCUMENT NAME; Symbol; Count; 114 114 Total; Hole Size 3.937mil(0.100mm); Plated Plated; Hole Tolerance; 121 6 127 Total; Hole Size 3.937mil(0.10mm) 7.874mil(0.20mm); Plated Plated Plated; 3 3 4 356 Total; Plated Plated Non-Plated; Drill Table

Symbol | Count | Hole Size | Plated | Hole Tolerance

5 | 0.10mm | Plated
260 | 0.20mm | Plated
33 | 0.40mm | Plated
4 | 0.64mm | Plated
8 | 0.76mm | Plated
36 | 0.90mm | Plated

Drill Table - L7 Gnd - L8 Bottom

Drill Table - L1 Top - L2 Gnd

DRAWN R. Yoder | 10-4-2018

CHECKED A. Zbrzeski | 10-4-2018

NNP Power Module PCB,

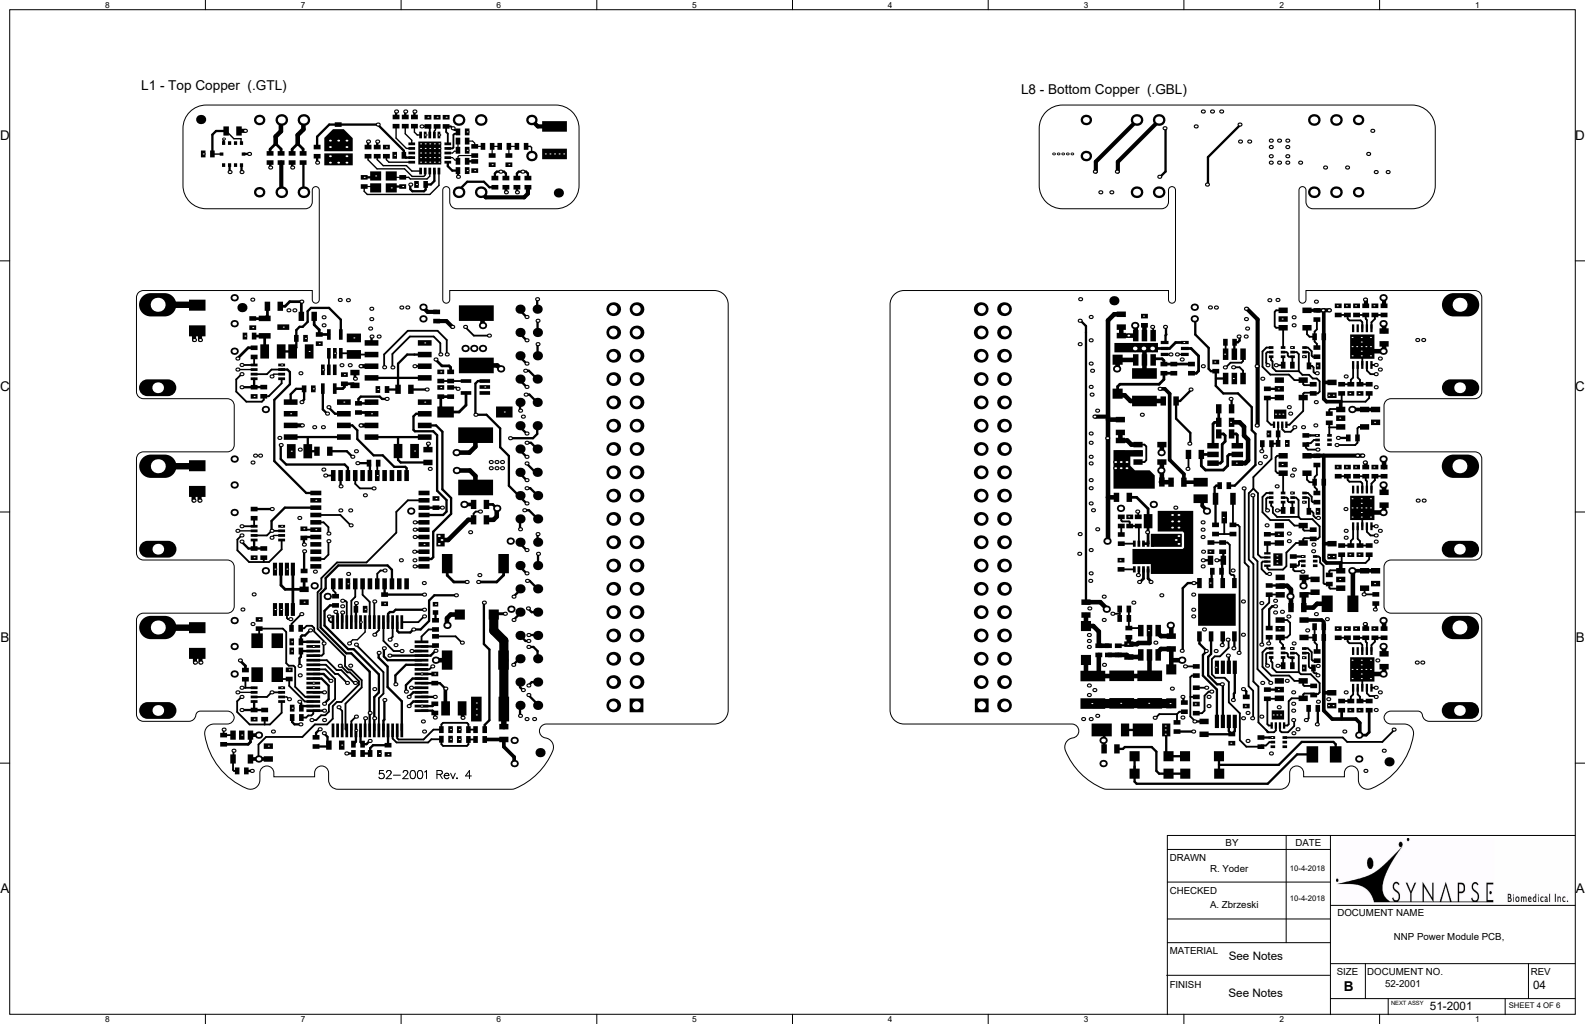
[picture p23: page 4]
DOCUMENT NAME; DRAWN; DATE; L1 - Top Copper (.GTL); L8 - Bottom Copper (.GBL)

R. Yoder

CHECKED A. Zbrzeski | 10-4-2018

NNP Power Module PCB,

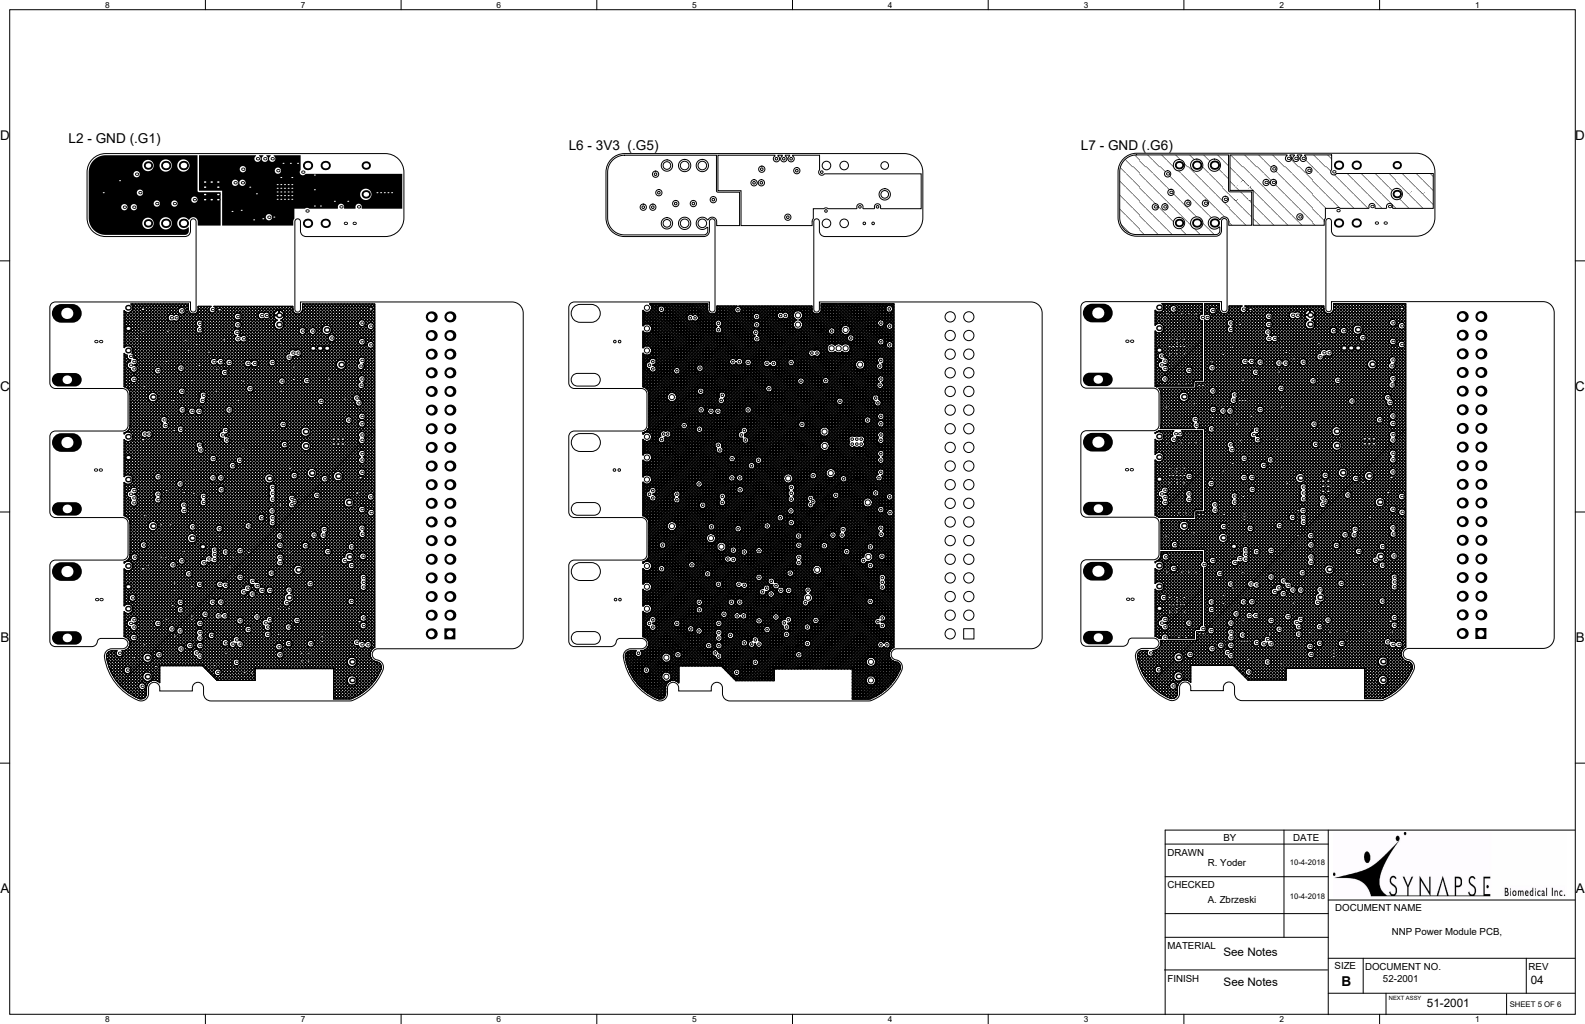
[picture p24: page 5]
DOCUMENT NAME; DATE; L2 - GND (.G1); L7 - GND (.G6)

DRAWN R. Yoder | 10-4-2018

CHECKED A. Zbrzeski | 10-4-2018

NNP Power Module PCB,

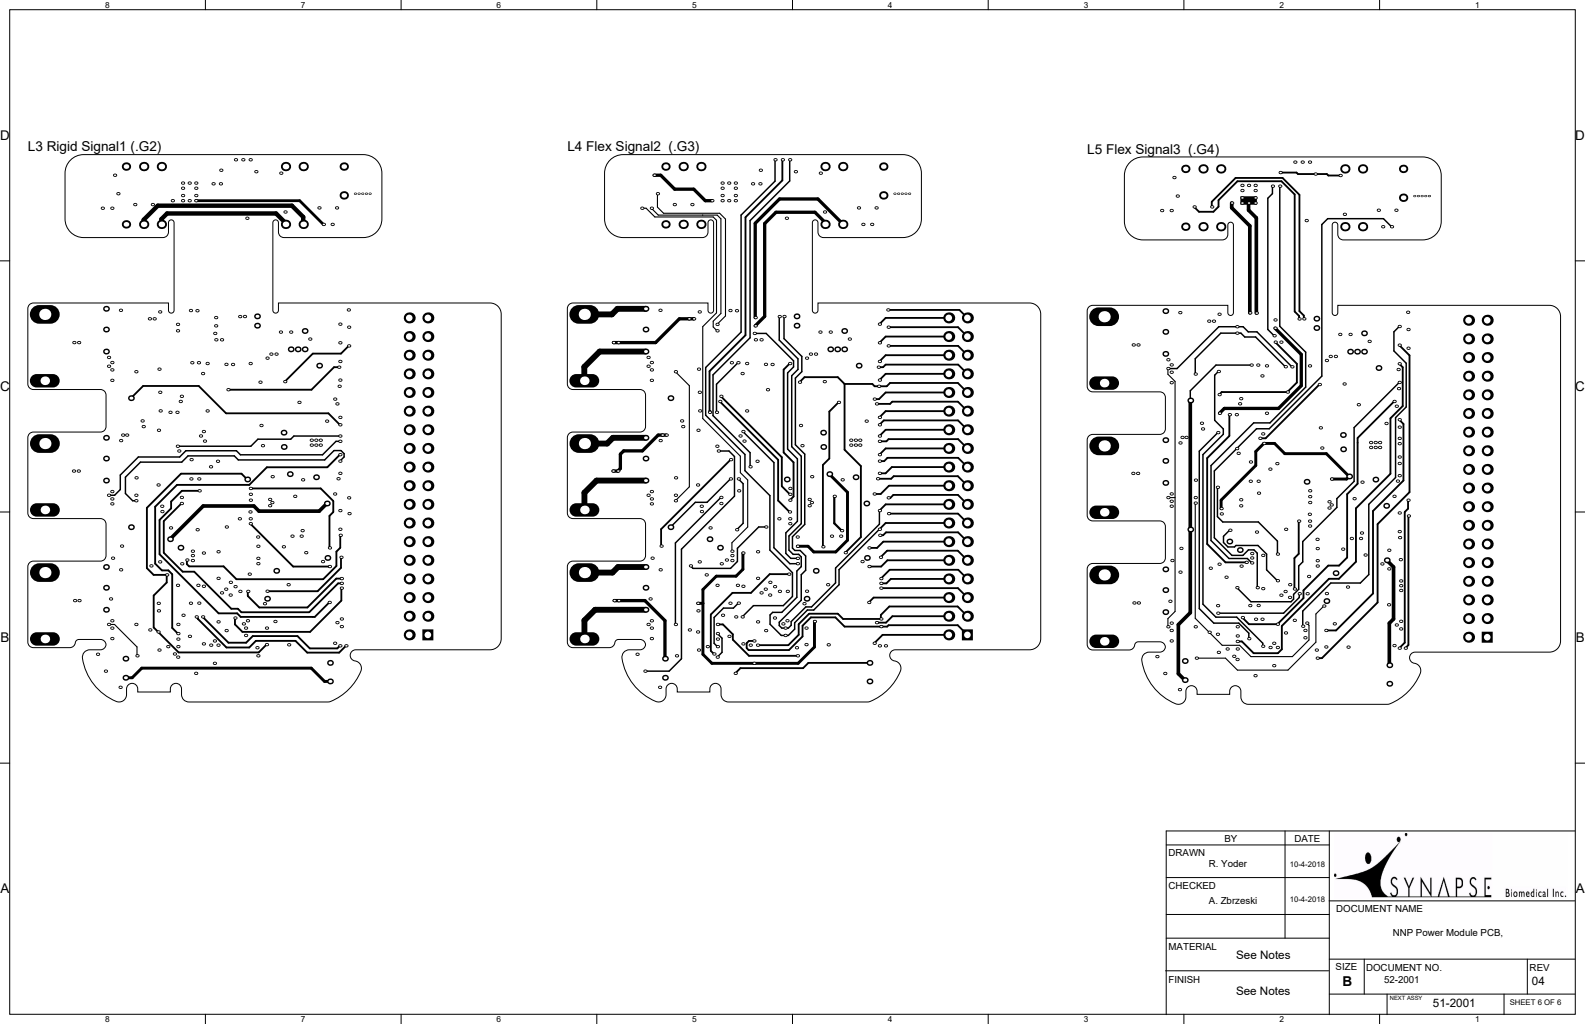
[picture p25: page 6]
DOCUMENT NAME; DATE; L3 Rigid Signal1 (.G2); L4 Flex Signal2 (.G3); L5 Flex Signal3 (.G4)

DRAWN R. Yoder | 10-4-2018

CHECKED A. Zbrzeski | 10-4-2018

NNP Power Module PCB,

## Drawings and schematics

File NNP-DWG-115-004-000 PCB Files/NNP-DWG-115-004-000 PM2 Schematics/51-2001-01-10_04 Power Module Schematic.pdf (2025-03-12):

ECN | DESCRIPTION | REV | DATE | REV. SHT. DWG. NO.
-14 | RADIO SYSTEM

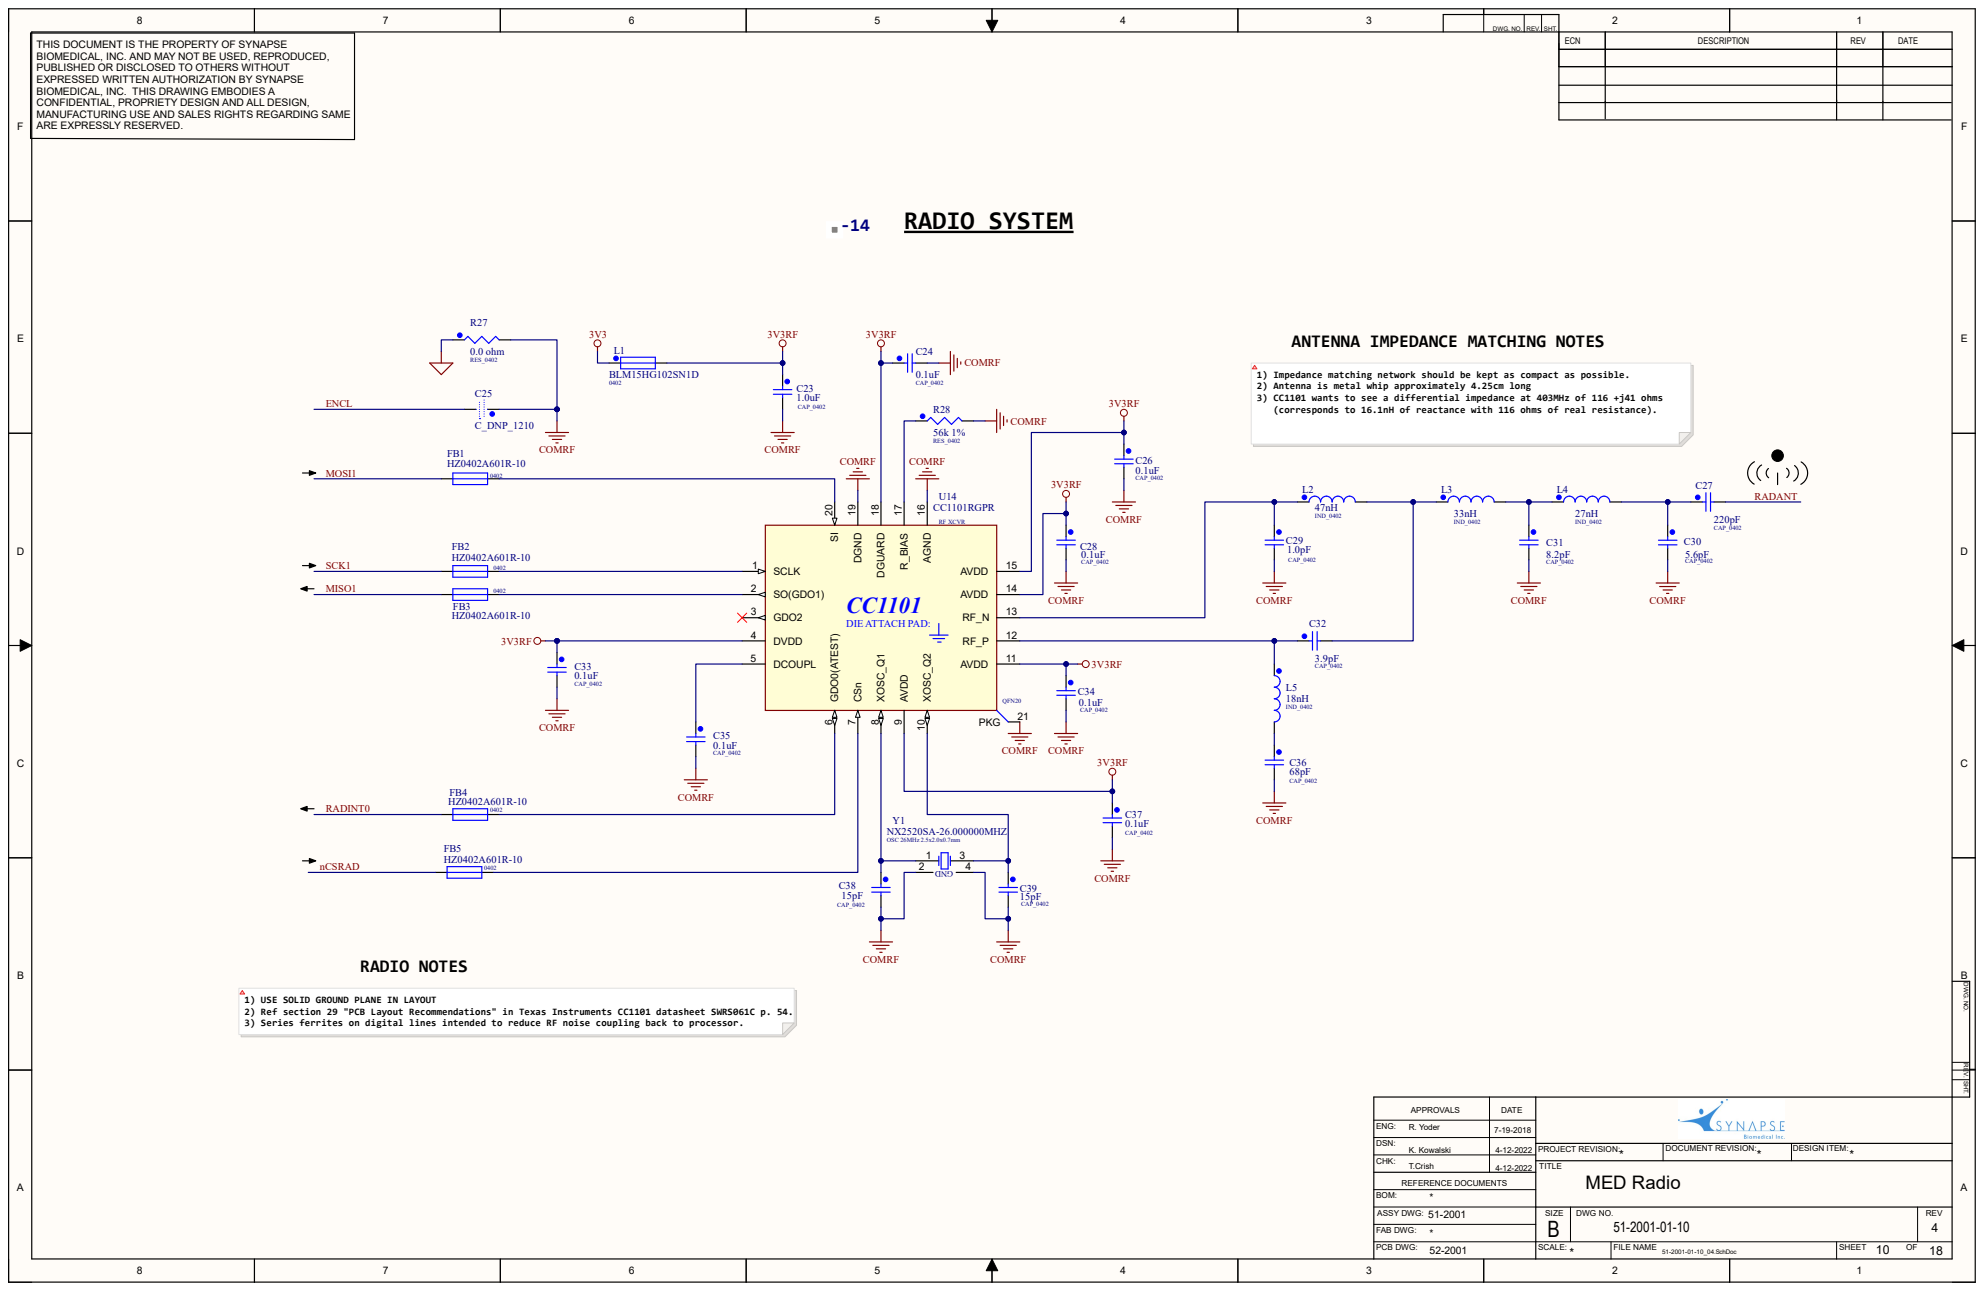
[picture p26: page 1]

DWG. NO. | REV. | SHT.

THIS DOCUMENT IS THE PROPERTY OF SYNAPSE BIOMEDICAL, INC. AND MAY NOT BE USED, REPRODUCED, PUBLISHED OR DISCLOSED TO OTHERS WITHOUT EXPRESSED WRITTEN AUTHORIZATION BY SYNAPSE BIOMEDICAL, INC. THIS DRAWING EMBODIES A CONFIDENTIAL, PROPRIETY DESIGN AND ALL DESIGN, MANUFACTURING USE AND SALES RIGHTS REGARDING SAME ARE EXPRESSLY RESERVED. | 3V3RF

ANTENNA IMPEDANCE MATCHING NOTES

1) Impedance matching network should be kept as compact as possible.
2) Antenna is metal whip approximately 4.25cm long
3) CC1101 wants to see a differential impedance at 403MHz of 116 +j41 ohms
(corresponds to 16.1nH of reactance with 116 ohms of real resistance).

1) USE SOLID GROUND PLANE IN LAYOUT
2) Ref section 29 "PCB Layout Recommendations" in Texas Instruments CC1101 datasheet SWRS061C p. 54.
3) Series ferrites on digital lines intended to reduce RF noise coupling back to processor.

APPROVALS | DATE

ENG: R. Yoder | 7-19-2018

DSN: K. Kowalski | 4-12-2022

PROJECT REVISION: * | DOCUMENT REVISION: * | DESIGN ITEM: *

CHK: T.Crish | 4-12-2022

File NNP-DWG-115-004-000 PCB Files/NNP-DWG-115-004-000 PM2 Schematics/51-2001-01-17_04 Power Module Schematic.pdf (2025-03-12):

ECN | DESCRIPTION | REV | DATE | REV. SHT. DWG. NO.

# -41 Microcontroller System

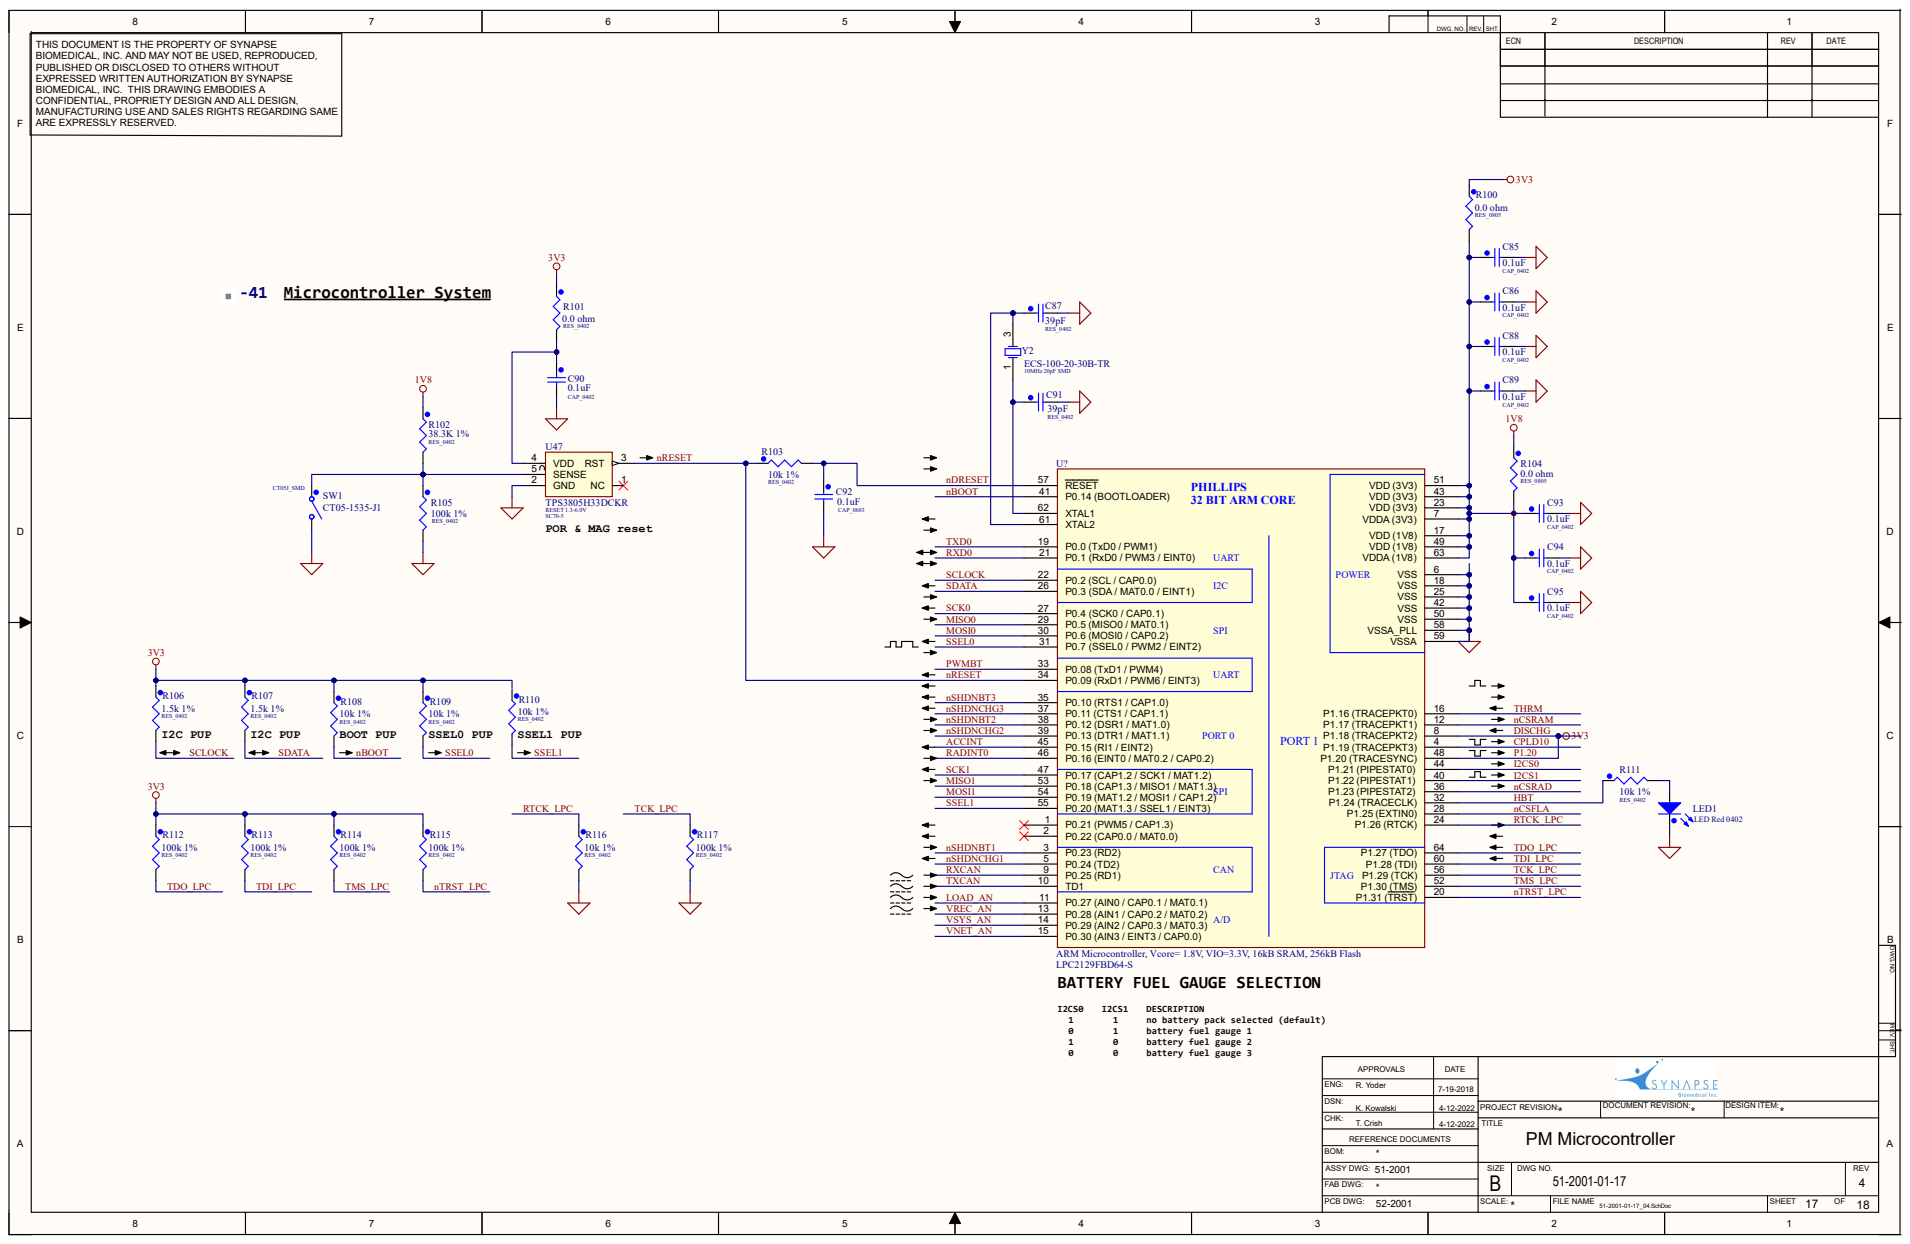
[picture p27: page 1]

DWG. NO. | REV. | SHT.

THIS DOCUMENT IS THE PROPERTY OF SYNAPSE BIOMEDICAL, INC. AND MAY NOT BE USED, REPRODUCED, PUBLISHED OR DISCLOSED TO OTHERS WITHOUT EXPRESSED WRITTEN AUTHORIZATION BY SYNAPSE BIOMEDICAL, INC. THIS DRAWING EMBODIES A CONFIDENTIAL, PROPRIETY DESIGN AND ALL DESIGN, MANUFACTURING USE AND SALES RIGHTS REGARDING SAME ARE EXPRESSLY RESERVED. | 0.0 ohm RES_0805

ARM Microcontroller, Vcore= 1.8V, VIO=3.3V, 16kB SRAM, 256kB Flash
LPC2129FBD64-S
BATTERY FUEL GAUGE SELECTION

DESCRIPTION
no battery pack selected (default)

APPROVALS | DATE

ENG: R. Yoder | 7-19-2018

DSN: K. Kowalski | 4-12-2022

PROJECT REVISION: * | DOCUMENT REVISION: * | DESIGN ITEM: *

CHK: T. Crish | 4-12-2022

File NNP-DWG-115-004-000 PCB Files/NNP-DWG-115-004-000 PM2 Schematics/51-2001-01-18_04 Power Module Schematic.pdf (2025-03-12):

ECN | DESCRIPTION | REV | DATE | REV. SHT. DWG. NO.
ANALOG PERIPHERAL SYSTEM -43 | SCLOCK1

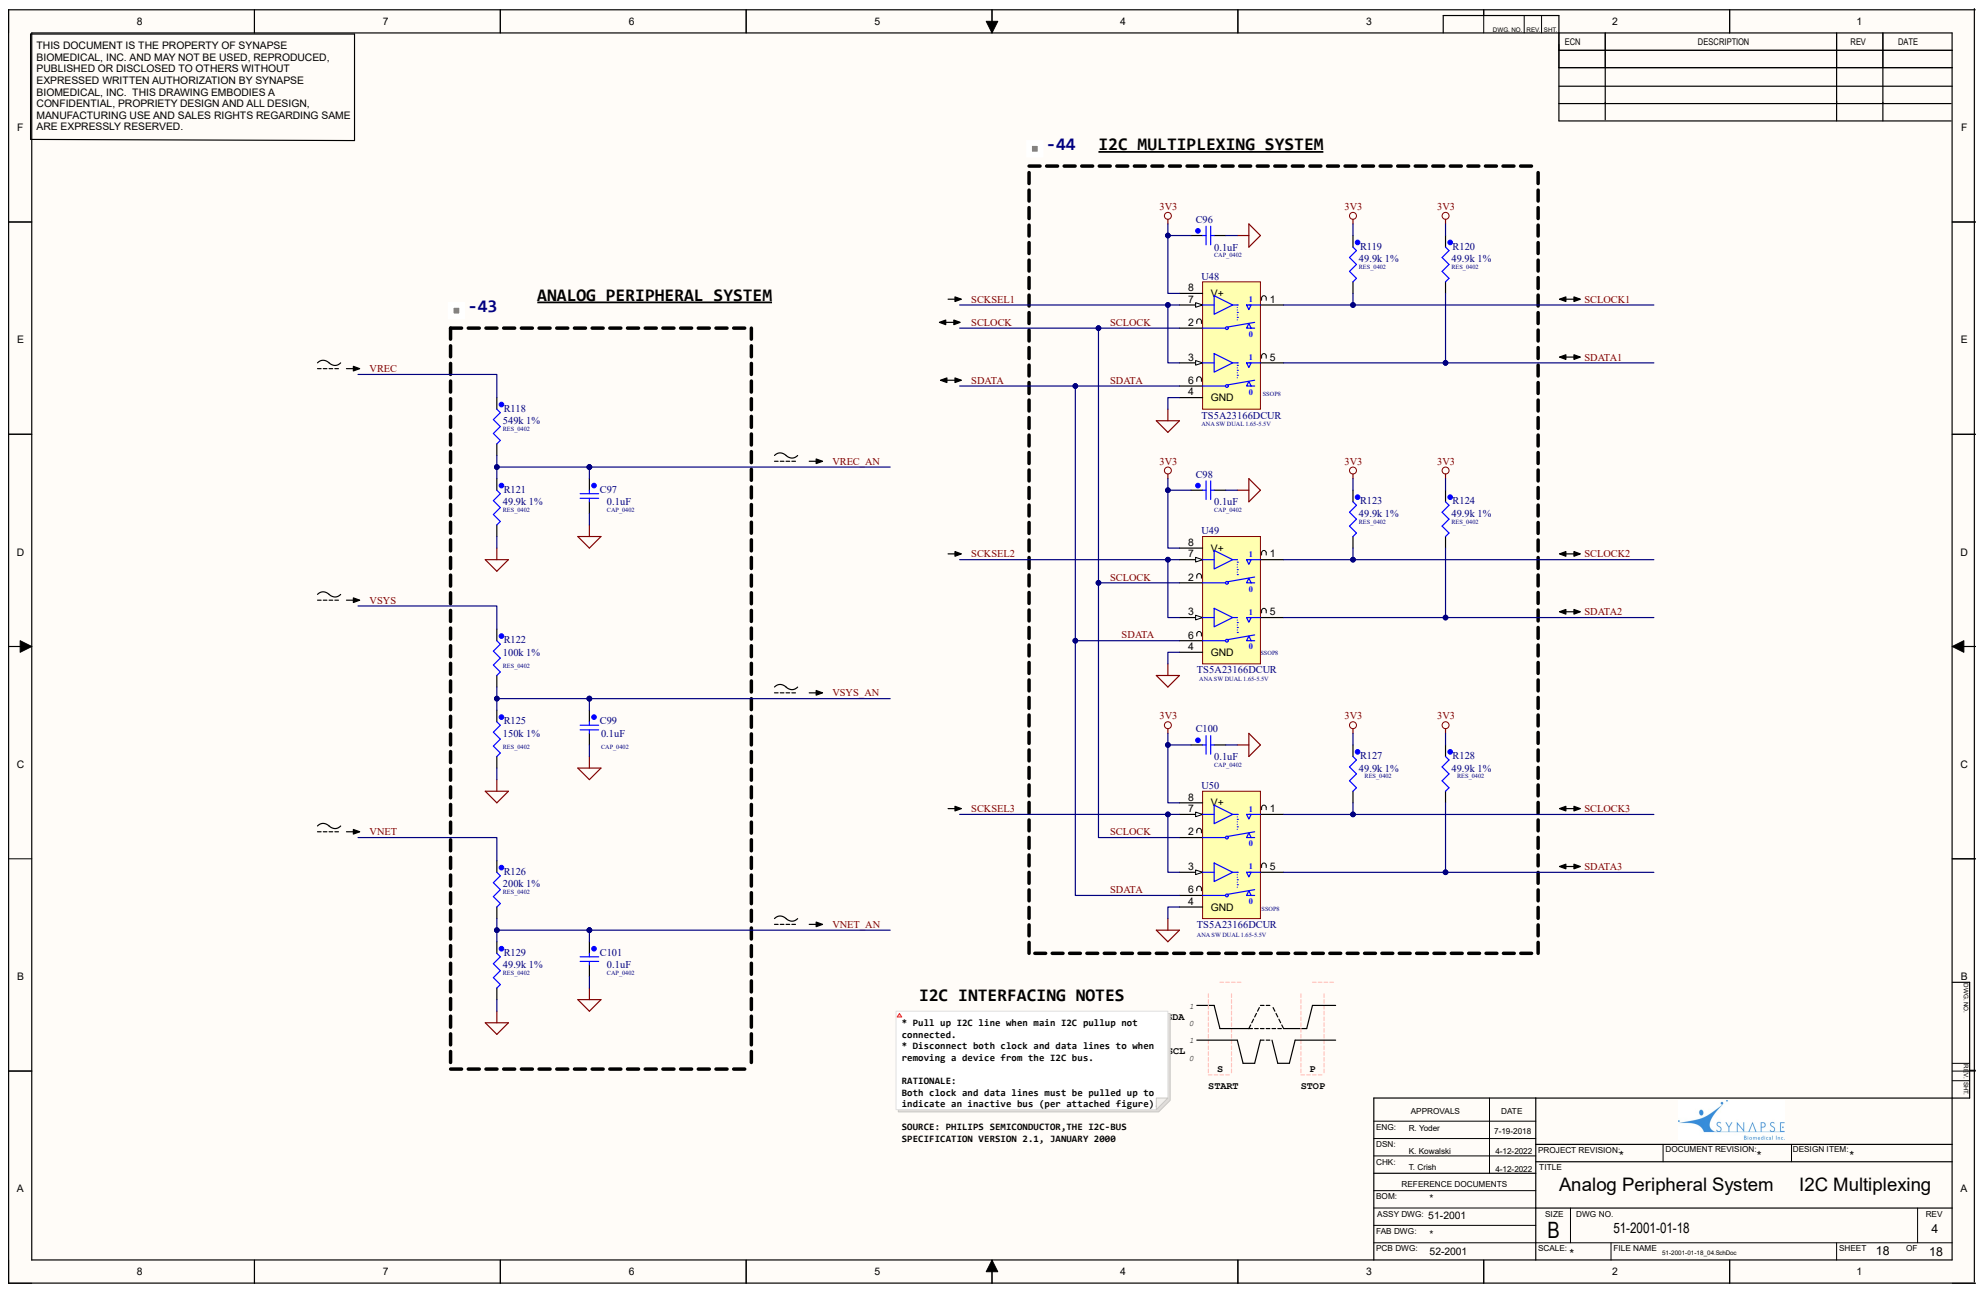
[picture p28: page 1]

DWG. NO. | REV. | SHT.

THIS DOCUMENT IS THE PROPERTY OF SYNAPSE BIOMEDICAL, INC. AND MAY NOT BE USED, REPRODUCED, PUBLISHED OR DISCLOSED TO OTHERS WITHOUT EXPRESSED WRITTEN AUTHORIZATION BY SYNAPSE BIOMEDICAL, INC. THIS DRAWING EMBODIES A CONFIDENTIAL, PROPRIETY DESIGN AND ALL DESIGN, MANUFACTURING USE AND SALES RIGHTS REGARDING SAME ARE EXPRESSLY RESERVED. | -44 I2C MULTIPLEXING SYSTEM

* Pull up I2C line when main I2C pullup not
connected.
* Disconnect both clock and data lines to when
removing a device from the I2C bus.

RATIONALE:
Both clock and data lines must be pulled up to
indicate an inactive bus (per attached figure).

APPROVALS | DATE

SOURCE: PHILIPS SEMICONDUCTOR,THE I2C-BUS
SPECIFICATION VERSION 2.1, JANUARY 2000

ENG: R. Yoder | 7-19-2018

DSN: K. Kowalski | 4-12-2022

PROJECT REVISION: * | DOCUMENT REVISION: * | DESIGN ITEM: *

CHK: T. Crish | 4-12-2022

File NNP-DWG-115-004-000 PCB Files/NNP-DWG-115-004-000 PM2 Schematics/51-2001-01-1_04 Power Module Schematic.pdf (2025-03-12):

ECN | DESCRIPTION | REV | DATE | REV. SHT. DWG. NO.

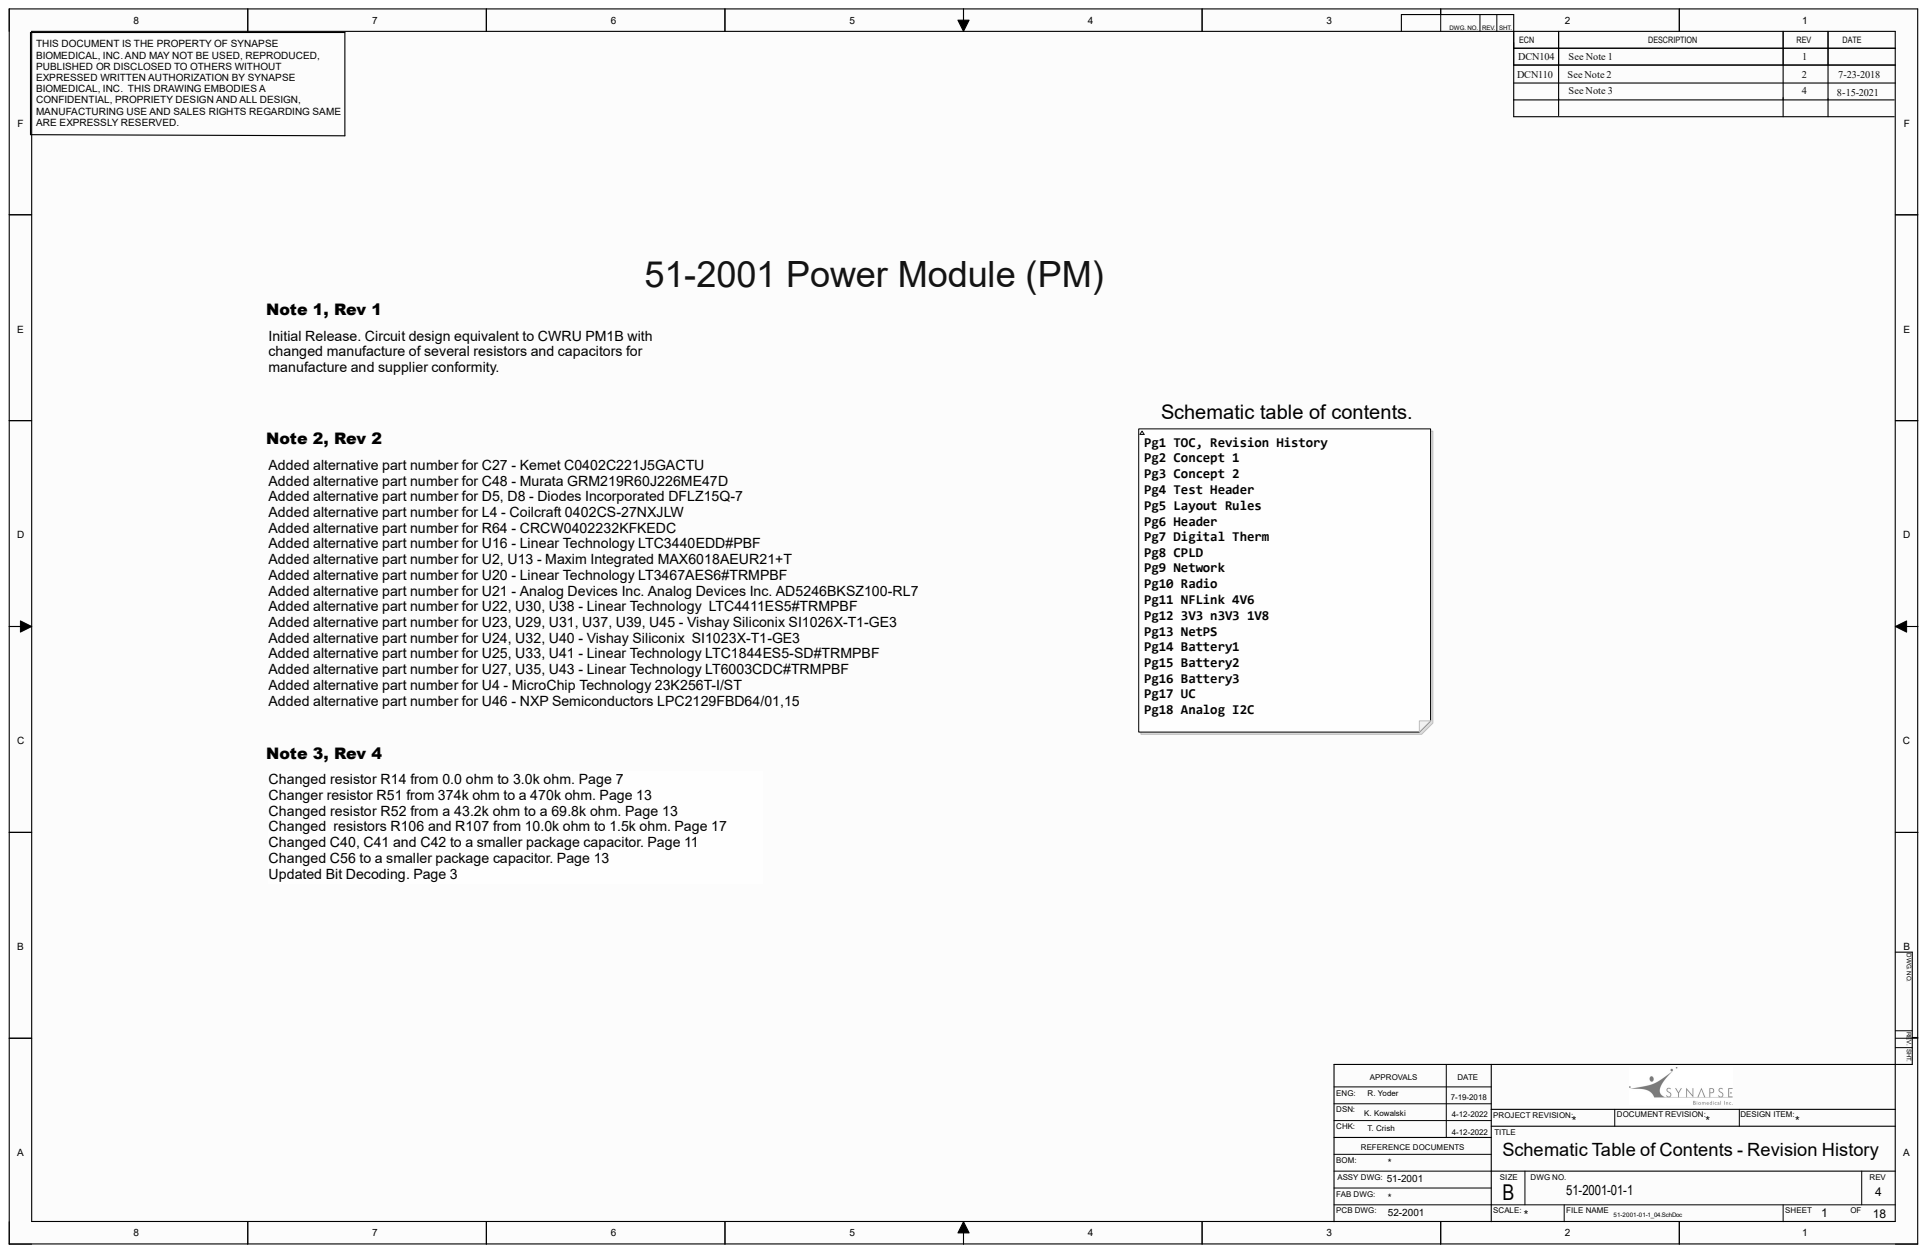
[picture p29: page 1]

8 | 7 | 6 | 5 | 4 | 3 | DWG. NO. | REV. | SHT. | 2 | 1

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

DCN104 | See Note 1 | 1
DCN110 | See Note 2 | 2 | 7-23-2018

See Note 3 | 4 | 8-15-2021

Initial Release. Circuit design equivalent to CWRU PM1B with
changed manufacture of several resistors and capacitors for
manufacture and supplier conformity.

Schematic table of contents.

Added alternative part number for C27 - Kemet C0402C221J5GACTU
Added alternative part number for C48 - Murata GRM219R60J226ME47D
Added alternative part number for D5, D8 - Diodes Incorporated DFLZ15Q-7
Added alternative part number for L4 - Coilcraft 0402CS-27NXJLW
Added alternative part number for R64 - CRCW0402232KFKEDC
Added alternative part number for U16 - Linear Technology LTC3440EDD#PBF
Added alternative part number for U2, U13 - Maxim Integrated MAX6018AEUR21+T
Added alternative part number for U20 - Linear Technology LT3467AES6#TRMPBF
Added alternative part number for U21 - Analog Devices Inc. Analog Devices Inc. AD5246BKSZ100-RL7
Added alternative part number for U22, U30, U38 - Linear Technology LTC4411ES5#TRMPBF
Added alternative part number for U23, U29, U31, U37, U39, U45 - Vishay Siliconix SI1026X-T1-GE3
Added alternative part number for U24, U32, U40 - Vishay Siliconix SI1023X-T1-GE3
Added alternative part number for U25, U33, U41 - Linear Technology LTC1844ES5-SD#TRMPBF
Added alternative part number for U27, U35, U43 - Linear Technology LT6003CDC#TRMPBF
Added alternative part number for U4 - MicroChip Technology 23K256T-I/ST
Added alternative part number for U46 - NXP Semiconductors LPC2129FBD64/01,15

Changed resistor R14 from 0.0 ohm to 3.0k ohm. Page 7
Changer resistor R51 from 374k ohm to a 470k ohm. Page 13
Changed resistor R52 from a 43.2k ohm to a 69.8k ohm. Page 13
Changed resistors R106 and R107 from 10.0k ohm to 1.5k ohm. Page 17
Changed C40, C41 and C42 to a smaller package capacitor. Page 11
Changed C56 to a smaller package capacitor. Page 13
Updated Bit Decoding. Page 3

APPROVALS | DATE

ENG: R. Yoder | 7-19-2018
CHK: T. Crish | 4-12-2022 | TITLE Schematic Table of Contents - Revision History

DSN: K. Kowalski | 4-12-2022 | PROJECT REVISION: | DOCUMENT REVISION: * | DESIGN ITEM: * *

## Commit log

2024-08-27 Uploading Power Module CAD Data
    [NNP-DWG-110-001-000 Port Plug, Handle Overmold, Blue.SLDPRT, NNP-DWG-110-001-000 Port Plug, Handle Overmold, Blue.STEP, NNP-DWG-110-001-001 Port Plug, Handle O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]
2024-08-27 Adding exploded view in CAD
2025-03-12 Posting PM2 PCB source files
    [51-2001-01-10_04 Power Module Schematic.SchDoc, 51-2001-01-11_04 Power Module Schematic.SchDoc, 51-2001-01-12_04 Power Module Schematic.SchDoc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]
